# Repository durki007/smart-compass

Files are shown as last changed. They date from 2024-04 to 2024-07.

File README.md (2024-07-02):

# Smart Compass - Inteligentne urządzenie do nawigacji
## O projekcie
Projekt Smart Compass był realizowany w ramach kursu "Projekt Zespołowy" na VI semestrze studiów inżynierskich, na kierunku Informatyka Techniczna na Politechnice Wrocławskiej.

Celem projektu było zaprojektowanie urządzenia elektronicznego, działającego w trybie autonomicznym, pozwalającego na nawigację po prostej trasie składającej się z dowolnej liczby kolejnych punktów.

## Stan końcowy projektu
W ramach projektu zostały wykonane:
- [Aplikacja mobilna](https://github.com/durki007/smart-compass/tree/main/app) wykonana w technologii `React Native`. 
- [Schemat układu elektronicznego](https://github.com/durki007/smart-compass/tree/main/hardware)
- [Firmware urządzenia](https://github.com/durki007/smart-compass/tree/main/hardware) w języku `C` i frameworku `ESP-IDF`.

> Poszczególne częsci projektu, oraz instrukcje kompilacji i uruchomienia znajdują się w podfolderach repozytorium.

## Autorzy
- Dominik Cybulski
- Michał Durkalec
- Stanisław Kurzyp

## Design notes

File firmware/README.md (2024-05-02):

# SmartCompass Firmware
## About
This is the firmware for the ESP32 microcontroller that is part of the **Smart Compass** project.
> BLE configuration is based on the [ESP-IDF nimble/bleprph example](https://github.com/espressif/esp-idf/tree/5a40bb8746633477c07ff9a3e90016c37fa0dc0c/examples/bluetooth/nimble/bleprph)

## Project structure
The project is organized as follows:
```
firmware/ 
│   main/ -- Application code entry point
│   components/
│   ├── sc_ble      -- BLE configuration and services
│   ├── sc_compass  -- Compass sensor driver
│   ├── sc_display  -- Display driver
│   ├── sc_gps      -- GPS sensor driver
```
The `main` folder contains the entry point of the application. All tasks are created and initialized here.

The `components` folder contains the drivers for the sensors and the BLE configuration.
Each component defines a set of functions to initialize, read, and write data to the sensor.

### Third party components
Refer to `.gitmodules` for exact information. 
>To avoid dependency issues, use the correct versions of components.

Components used:
- [lvgl v8.3](https://github.com/lvgl/lvgl.git)
- [lvgl_esp32_drivers](https://github.com/hiruna/lvgl_esp32_drivers.git)
Fork by [hiruna](https://github.com/hiruna) with some modifications to work with the latest version of `lvgl` and `esp-idf v.5.2`.
## Build
#### Prerequisites
- [ESP-IDF v.5.2.1](https://docs.espressif.com/projects/esp-idf/en/stable/esp32/get-started/index.html#manual-installation)
- [Python 3.11.2](https://www.python.org/downloads/release/python-3112/)
> When using `ESP-IDF-v5.2.1`: `Python3.11.2` must be used. This is related to a known [issue](https://github.com/espressif/esp-idf/issues/12519).
### Using ESP-IDF
Set target to `esp32`:
```bash
idf.py set-target esp32
```
Build
```bash
idf.py build
```
### CMake on Windows
#### Prerequisites
- [CMake](https://cmake.org/download/)
- Ninja (or other build system)
- [ESP-IDF v.5.2.1](https://docs.espressif.com/projects/esp-idf/en/stable/esp32/get-started/index.html#manual-installation)
with all related environment variables set.

Generate build files
```bash
mkdir build 
cd build
cmake -G Ninja ..
```
Build
```bash
ninja
```
All commands normally provided by `idf.py` can be used with `cmake` and `ninja` as well. For example, to configure the device:
```bash
ninja menuconfig
```

## Flash
```bash
idf.py -p PORT flash
```
Where `PORT` is the serial port where the ESP32 is connected. For example, on Windows, it could be `COM3`.

## References
- [ESP-IDF v5.2.1](https://docs.espressif.com/projects/esp-idf/en/stable/esp32/get-started/index.html#manual-installation)
- [ESP-IDF Build System](https://docs.espressif.com/projects/esp-idf/en/stable/esp32/api-guides/build-system.html) -- Building the project, configuring the device, defining components etc.

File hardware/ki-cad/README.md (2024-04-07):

# Pliki KiCad

Pliki w tym folderze zostały udostępnione w celu odtworzenia projektu schematu i ich edycji w programie KiCad.

### Lista plików
- compass-schematic.kicad_sh - Plik odpowiedzialny za schemat prototypu, skopiowany z projektu o nazwie compass-schematics 
- Compass.kicad_sym - Plik biblioteki symboli stworzonych ręcznie dla urządzeń peryferyjnych
- Compass.bak - Plik wygenerowany dla biblioteki symboli, o nie do końca znanej funkcji, załączony na wypadek problemów w z blblioteką (prawdopodobnie plik back-up)

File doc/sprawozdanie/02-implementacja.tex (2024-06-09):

\part{Implementacja}

\section{Projekt urządzenia}

Urządzenie zostało zaprojektowane z myślą o maksymalnej prostocie, w związku z czym nie występuje żadna magistrala, a wszystkie moduły podłączone są wedle architektury punkt-punkt. Głównym elementem urządzenia jest płytka prototypowa {\bf DevKitV4 ESP-WROOM-32E}, zawierająca zaprogramowaną logikę sterowania oraz wbudowany moduł Bluetooth/WiFi.\\

Do urządzeń peryferyjnych należą:
\begin{itemize}
    \item Wyświetlacz LCD Waveshare 1.8inch 128x160
    \item Magnetometr cyfrowy 3-osiowy HMC5883L
    \item GPS GY-NEO6MV2 z anteną
\end{itemize}

Schemat podłączenia wszystkich elementów zaprezentowano na rysunku \ref{fig:scheme:hardware}.

\begin{figure}[H]
    \centering
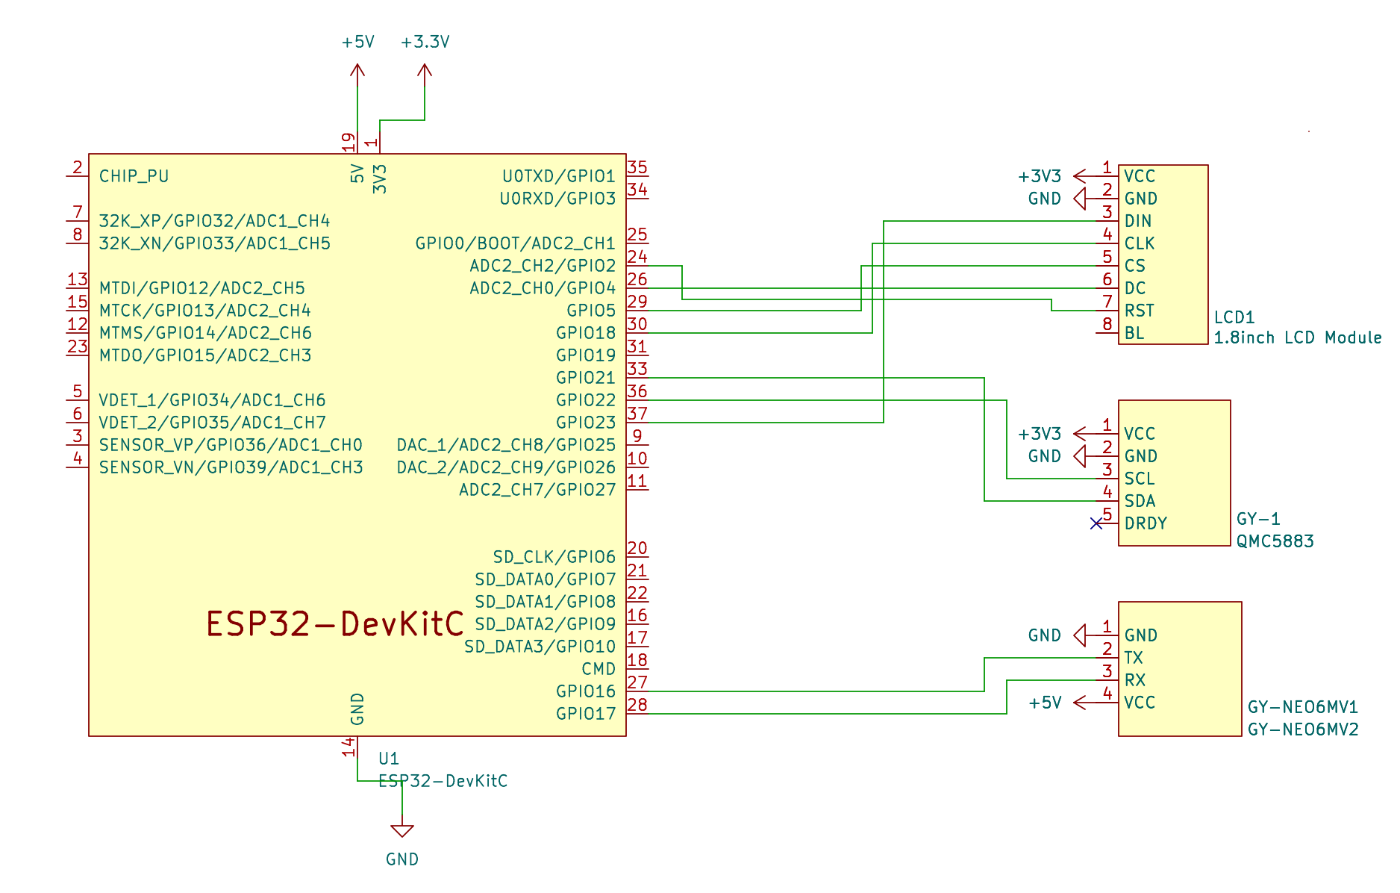
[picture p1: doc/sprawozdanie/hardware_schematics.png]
    
    \caption{Schemat prototypu urządzenia}
    \label{fig:scheme:hardware}
\end{figure}

\subsection{Kosztorys prototypu}
Kosztorys uwzględnia ceny głównych modułów urządzenia. Dotychczasowe koszty zostały pokryte przez członków grupy projektowej. Posiadamy również inne niezbędne części podstawowe, takie jak rezystory, kondensatory czy przyciski, które będą niezbędne przy testowaniu prototypu.

\begin{table}[h]
    \centering
    \begin{tabular}{|l|l|r|r|}
        \hline
        \textbf{Nazwa części} & \textbf{Typ}                 & \textbf{Cena detaliczna} & \textbf{Faktyczny koszt} \\ \hline
        Espressif DevKitV4    & ESP-WROOM-32E                & 35,99 zł                 & 35,99 zł                 \\ \hline
        GY-273                & Magnetometr cyfrowy 3-osiowy & 17,00 zł                 & 13,71 zł                 \\ \hline
        GY-NEO6MV2            & Moduł GPS z anteną           & 27,99 zł                 & 27,99 zł                 \\ \hline
        Waveshare 13892       & Wyświetlacz LCD 128x160px    & 33,90 zł                 & 0,00 zł                  \\ \hline
        \textbf{Razem}        &                              & \textbf{114,88 zł}       & \textbf{77,69 zł}        \\ \hline
    \end{tabular}
    \caption{Kosztorys prototypu}
\end{table}

\subsection{DevKitV4 ESP-WROOM-32E}

DevKitV4 ESP-WROOM-32E to zaawansowany moduł mikroprocesorowy z serii ESP32. Łączy w sobie  wysoką wydajność, niskie zużycie energii i wszechstronność. Wyposażony jest w podwójny rdzeń, obsługujący taktowanie do 240 MHz, oraz wbudowane Wi-Fi i Bluetooth. Posiada szeroki zakres interfejsów, zapewniając elastyczność w przypadku podłączania z modułami peryferyjnymi.

\subsection{LCD Waveshare 1.8inch 128x160}

Waveshare 1.8inch 128x160 to kolorowy wyświetlacz TFT o rozdzielczości 128x160 pikseli. Oferuje jasny i wyraźny obraz, umożliwiający wyświetlanie tekstu, grafiki i prostych animacji. Dane przesyłane są poprzez interfejs SPI.

\subsection{Mangetometr HMC5883L}

HMC5883L to trójosiowy magnetometr cyfrowy, który może mierzyć pole magnetyczne ziemi, co pozwala na określenie orientacji przestrzennej i wykorzystanie w roli kompasu. Dane odczytywane są poprzez interfejs I2C.

\subsection{GPS GY-NEO6MV2}

GY-NEO6MV2 to moduł GPS oparty na układzie NEO-6M, który umożliwia precyzyjne śledzenie pozycji geograficznej poprzez komunikację z satelitą za pomocą podłączonej anteny. Dane przezkazywane są poprzez standardowy interfejs UART.

\subsection{Napotkane problemy}

Podczas programowania oraz testowania komunikacji mikroprocesora z urządzeniami peryferyjnymi napotkano problemy z obsługą modułu GPS oraz magnetometru. \\

W przypadku połączenia z modułem GPS, wykryto wadliwość 2 z 4 zamówionych urządzeń - po wyznaczeniu oraz podłączeniu działających komponentów, nie wystąpiły już dalsze problemy. \\

W przypadku obsługi magnetometru pojawiały się problemy wydające się losowe w chwili próby nawiązania połączenia master-slave z modułem. Problemy te niekiedy zakłócały działanie całego programu załadowanego do mikroprocesora, niekiedy nie występowały, w innych przypadkach zaś powodowały błąd watchdoga w linii inicjalizacji sterownika I2C. Sterownik zawieszał się, oczekując transmisji na linii danych, które nigdy się nie pojawiały. Problem zidentyfikowano w błędzie implementacji sterownika I2C przez ESP-IDF. Użycie starszej wersji sterownika trwale usunęło problem. 

\section{Firmware}
Firmware aplikacji został napisany w języku C z wykorzystaniem platformy ESP-IDF \cite{esp-idf}.
ESP-IDF to oficjalne środowisko programistyczne dla platformy ESP32, które zawiera narzędzia do budowania, debugowania i wgrywania oprogramowania na urządzenie.

\subsection{Modularna struktura kodu} \label{sec:modularna-struktura-kodu}
Framework ESP-IDF pozwala na tworzenie projektów w sposób modułowy, co pozwala na łatwe dodawanie nowych funkcjonalności i niezależne testowanie poszczególnych komponentów.
W projekcie wyróżniono następujące moduły (komponenty):
\begin{itemize}
    \item \textbf{main} - moduł główny, inicjalizuje pozostałe moduły i definiuje zmienne współdzielone.
    \item \textbf{sc\_ble} - moduł odpowiedzialny za obsługę protokołu BLE. Zawiera definicje usług i charakterystyk GATT.
    \item \textbf{sc\_gps} - moduł obsługujący moduł GPS. Zawiera funkcje do odczytu współrzędnych geograficznych.
    \item \textbf{sc\_compass} - moduł obsługujący magnetometr. Zawiera funkcje do odczytu kierunku kompasu.
    \item \textbf{sc\_display} - moduł obsługujący wyświetlacz LCD. Zawiera funkcje do wyświetlania informacji na ekranie z wykorzystaniem biblioteki LVGL.
    \item \textbf{sc\_logic} - moduł odpowiedzialny za logikę aplikacji. Zawiera funkcje do obliczania kierunku i dystansu do celu.
    \item \textbf{lvgl} - moduł zawierający bibliotekę LVGL. \cite{lvgl-esp32-port} Zawiera konfigurację i funkcje pomocnicze do obsługi wyświetlacza.
    \item \textbf{lvgl\_esp32\_drivers} - moduł zawierający sterowniki dla ESP32 do biblioteki LVGL. \cite{lvgl-esp32-drivers}
\end{itemize}

\subsection{Architektura wielowątkowa}
Framework ESP-IDF jest oparty na architekturze FreeRTOS \cite{freertos-docs}, co pozwala na tworzenie wielowątkowych aplikacji.
Zawarta we frameworku wersja FreeRTOS pozwala na wykorzystanie dwóch rdzeni procesora ESP32, zapewniając równoległe wykonywanie zadań w dwóch wątkach.
Każdy z modułów aplikacji opisanych w sekcji \ref{sec:modularna-struktura-kodu} działa w osobnym wątku.

\subsubsection{Zmienne współdzielone}
Program zawiera dwie zmienne współdzielone odpowiedzialne za przechowywanie aktualnych danych na temat odczytów z sensorów oraz przechowywanie aktualnych danych do wyświetlenia na ekranie.

\begin{lstlisting}[language=C, caption=Definicja zmiennej dla odczytów sensorów]
typedef struct {
    SemaphoreHandle_t mutex;
    compass_position_t position;
    float bearing; // in radians
    float bearing_deg; // in degrees
    compass_path_t path;
    bool position_updated;
} compass_data_t;
\end{lstlisting}

\begin{lstlisting}[language=C, caption=Definicja zmiennej dla danych wynikowych]
typedef struct {
    SemaphoreHandle_t mutex;
    // Angle in 0.1 degrees - between 0 and 3600
    int16_t angle;
    // Next waypoint id
    uint16_t next_wp;
    // Distance to next waypoint in meters
    uint32_t distance;
    bool finished;
} display_data_t;
\end{lstlisting}

Każda zmienna posiada semafor, który zapewnia dostęp do zasobu w sposób atomowy, co zapobiega konfliktom między wątkami.

\subsection{Protokół komunikacji Bluetooth Low Energy (BLE)}
Protokół komunikacji BLE został zaimplementowany zgodnie ze standardem Bluetooth Core 4.2 \cite{bluetooth-core-spec-4-2} na platformie ESP32.
Użyto stosu i ESP-NimBLE \cite{esp-idf-nimble-docs}, który zapewni odpowiednie zarządzanie pamięcią oraz obsługę komunikacji BLE.
Stos ESP-NimBLE jest alternatywną wersją stosu Apache MyNewt Nimble \cite{apache-mynewt-docs}, przystosowaną do pracy z mikrokontrolerami producenta Espressif.

\subsubsection{Obsługa po stronie urządzenia}
Urządzenie wykorzystuje stos ESP-NimBLE do implementacji protokołu BLE, co pozwala na zmniejszenie zużycia pamięci.
Komunikacja z aplikacją mobilną opiera się na deklaracji usług i charakterystyk GATT, umożliwiając przesyłanie danych trasy w postaci tablic par współrzędnych geograficznych.

\begin{lstlisting}[language=C, caption=Definicja charakterystyki GATT]
static uint8_t gatt_svr_chr_val[MAX_CHAR_LEN];
static uint16_t gatt_svr_chr_val_handle;
static const ble_uuid128_t gatt_svr_chr_uuid =
        BLE_UUID128_INIT(0x00, 0x00, 0x00, 0x00, 0x11, 0x11, 0x11, 0x11,
                         0x22, 0x22, 0x22, 0x22, 0x33, 0x33, 0x33, 0x33);
\end{lstlisting}

\subsection{Napotkane problemy}
W trakcie rozwoju oprogramowania pojawiły się dwa główne problemy opisane w poniższych podrozdziałach.
\subsubsection{Konflikty między bibliotekami}
W trakcie rozwoju modułu odpowiedzialnego za komunikację z wyświetlaczem LCD pojawił się konflikt między:
\begin{itemize}
    \item Frameworkiem ESP-IDF
    \item Biblioteką LVGL,\cite{lvgl-esp32-port} która jest prostym silnikiem GUI
    \item Biblioteką LVGL ESP32 Drivers, \cite{lvgl-esp32-drivers} która zawiera sterowniki dla ESP32 do biblioteki LVGL
\end{itemize}
Początkowe próby integracji wszystkich trzech bibliotek w najnowszej wersji nie powiodły się,
co skutkowało koniecznością doboru kompatybilnych wersji bibliotek oraz dostosowaniem konfiguracji.
Proces naprawy konfliktów trwał kilka dni.

\subsubsection{Błąd w implementacji protokołu I2C w bibliotece ESP-IDF}
Do komunikacji z magnetometrem QMC5883 wykorzystano interfejs I2C \textit{(Inter Integrated Circut)}, który jest standardowym interfejsem komunikacyjnym dla urządzeń peryferyjnych.
Producent mikrokontrolera ESP32, firma Espressif, dostarcza bibliotekę do obsługi interfejsu I2C w ramach frameworku ESP-IDF.

W trakcie implementacji okazało się, że biblioteka ESP-IDF zawiera błąd w implementacji protokołu I2C, który uniemożliwiał poprawną komunikację z magnetometrem.
Dodatkowo, bład ten był niewykrywalny w procesie debugowania, co nie pozwalało na jednoznaczne zlokalizowanie problemu (mógł wynikać z błędu w kodzie, konfiguracji, podłęczeniu lub z uszkodzenia magnetometru).

Błąd naprawiono poprzez zastosowanie alternatywnej biblioteki do obsługi interfejsu I2C, co pozwoliło na poprawną komunikację z magnetometrem.

\section{Aplikacja mobilna}
Aplikacja mobilna spełnia następujące funkcjonalności:
\begin{itemize}
    \item rysowanie tras
    \item zapisywanie tras
    \item zarządzanie trasami
    \item nawiązywanie połączenia z urządzeniem SmartCompass
    \item przesyłanie tras do urządzenia SmartCompass
\end{itemize}

\subsection{Wykorzystane technologie}
Aplikacja została zrealizowana przy użyciu frameworku \textbf{React Native} \cite{react-native-docs} pozwalającego tworzyć jeden projekt, który następnie kompilowany jest do kodu aplikacji wykonywalnej na urządzeniach z Androidem jak i iOS. Ze względu na wymagania powiązane z uzyskaniem dostępu do modułu Bluetooth Low Energy urządzenia, zadecydowaliśmy się rozwijać naszą aplikację jedynie w kierunku systemu Android.
Ponadto wykorzystano platformę i zestaw narzędzi \textbf{Expo} \cite{expo-docs}, które upraszczają proces tworzenia, testowania i wdrażania aplikacji mobilnych.

\subsection{Wykorzystane biblioteki}

W aplikacji wykorzystano szereg bibliotek, które ułatwiły realizację poszczególnych funkcjonalności:

\begin{itemize}
    \item \textbf{react-native-async-storage} - Służy do przechowywania danych lokalnych na urządzeniu. Umożliwia łatwe zapisywanie i odczytywanie danych, takich jak ustawienia użytkownika czy trasy.
    \item \textbf{react-navigation} - Biblioteka do nawigacji w aplikacjach React Native. Umożliwia łatwe zarządzanie stosami ekranów, nawigację pomiędzy nimi oraz implementację różnorodnych wzorców nawigacji.
    \item \textbf{react-native-ble-plx} - Biblioteka do obsługi Bluetooth Low Energy (BLE). Umożliwia skanowanie, łączenie i komunikację z urządzeniami BLE, co jest kluczowe dla integracji z urządzeniem SmartCompass.
    \item \textbf{react-native-quick-base64} - Umożliwia szybkie kodowanie i dekodowanie danych w formacie base64, co jest przydatne przy przesyłaniu danych przez BLE.
    \item \textbf{react-native-vector-icons} - Biblioteka dostarczająca zestaw ikon do aplikacji. Umożliwia łatwe dodawanie ikon do przycisków, menu i innych elementów interfejsu użytkownika.
    \item \textbf{react-native-maps} - Biblioteka do integracji map w aplikacji. Umożliwia wyświetlanie map, rysowanie tras oraz interakcję z punktami na mapie.
    \item \textbf{react-native-reanimated} - Biblioteka do tworzenia płynnych i wydajnych animacji w aplikacji. Umożliwia tworzenie zaawansowanych animacji i interakcji, co poprawia ogólne wrażenia użytkownika.
\end{itemize}

\subsection{Tworzenie wersji \textit{release} aplikacji}
Pierwszym krokiem jest dodanie informacji takich jak nazwa, ikona, splash screen oraz konfiguracje specyficzne dla platformy Android do pliku \texttt{app.json}.

\begin{lstlisting}[caption=Plik app.json]
"expo": {
    "name": "app",
    "slug": "app",
    "version": "1.0.0",
    "orientation": "portrait",
    "icon": "./assets/icon.png",
    "plugins": [
      "react-native-ble-plx"
    ],
    "userInterfaceStyle": "light",
    "splash": {
      "image": "./assets/splash.png",
      "resizeMode": "contain",
      "backgroundColor": "#ffffff"
    },
}
\end{lstlisting}

należy również utworzyć konfigurację dla usługi \textbf{Expo Application Services (EAS)}, który jest częścią procesu budowania aplikacji. Konfigurację tą umieszcza się w pliku \texttt{eas.json}.

\begin{lstlisting}[caption=Plik eas.json]
{
  "cli": {
    "version": ">= 8.0.0"
  },
  "build": {
    "development": {
      "developmentClient": true,
      "distribution": "internal"
    },
    "preview": {
      "android": {
        "buildType": "apk"
      }
    },
    "production": {}
  },
  "submit": {
    "production": {}
  }
};
\end{lstlisting}

Dla klucza \texttt{preview} określamy typ budowania aplikacji jako \texttt{"apk"} dla platformy Android.
Następnie należy zalogować się do konta \textit{Expo}, a później, korzystając z komendy \texttt{'npx build -p android –profile preview'}, wygenerować plik \texttt{.apk}, który dostępny będzie do pobrania z konta użytkownika w platformie \textit{Expo}. Proces generowania pliku \texttt{.apk} jest zautomatyzowany i przeprowadzany przez narzędzie \textbf{Expo Build Service}. W przypadku naszej aplikacji rozwiązanie to znacząco ułatwia cały proces względem \textit{Bare Workflow}, czyli podejścia w którym nie wykorzystuje się frameworka \textit{Expo}.

\subsubsection{Różnice pomiędzy wersją testową, a \textit{release}}
Wersje testowe i release różnią się znacząco pod względem celu, konfiguracji, procesu budowania oraz dystrybucji. Wersje testowe są przeznaczone do szybkich iteracji i debugowania, zawierając narzędzia deweloperskie i umożliwiając natychmiastowe aktualizacje. Wersje release są zoptymalizowane pod kątem wydajności, stabilności i bezpieczeństwa, przeznaczone do dystrybucji do szerokiego grona użytkowników końcowych poprzez oficjalne sklepy aplikacji.

\subsection{Napotkane problemy}
Obsługa połączenia BLE z urządzeniem okazała się być trudniejsza niż zakładaliśmy, w szczególności monitorowanie sesji z poziomu aplikacji mobilnej. Cały proces wymaga również uzyskania odpowiednich pozwoleń od urządzenia na którym działa aplikacja, a proces testowania był utrudniony ponieważ posiadamy tylko jeden egzemplarz urządzenia SmartCompass. Ze względów technicznych UUID serwisu BLE naszego urządzenia SmartCompass został na sztywno ustawiony w aplikacji.

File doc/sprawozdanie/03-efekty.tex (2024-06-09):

\part{Efekty}

\section{Prototyp urządzenia}
Finalna wersja urządzenia została zmontowana na płytce prototypowej. (Rysunek \ref{fig:device})
Z przodu urządzenia widoczny jest wyświetlacz LCD i ceramiczna antena modułu GPS, z tyłu znajdują się mikrokontrolej na płytce prototypowej, moduł GPS i moduł magnetometru.
Prototyp korzysta z zasilania zewnętrznego poprzez kabel USB.

\begin{figure}[h]
    \centering
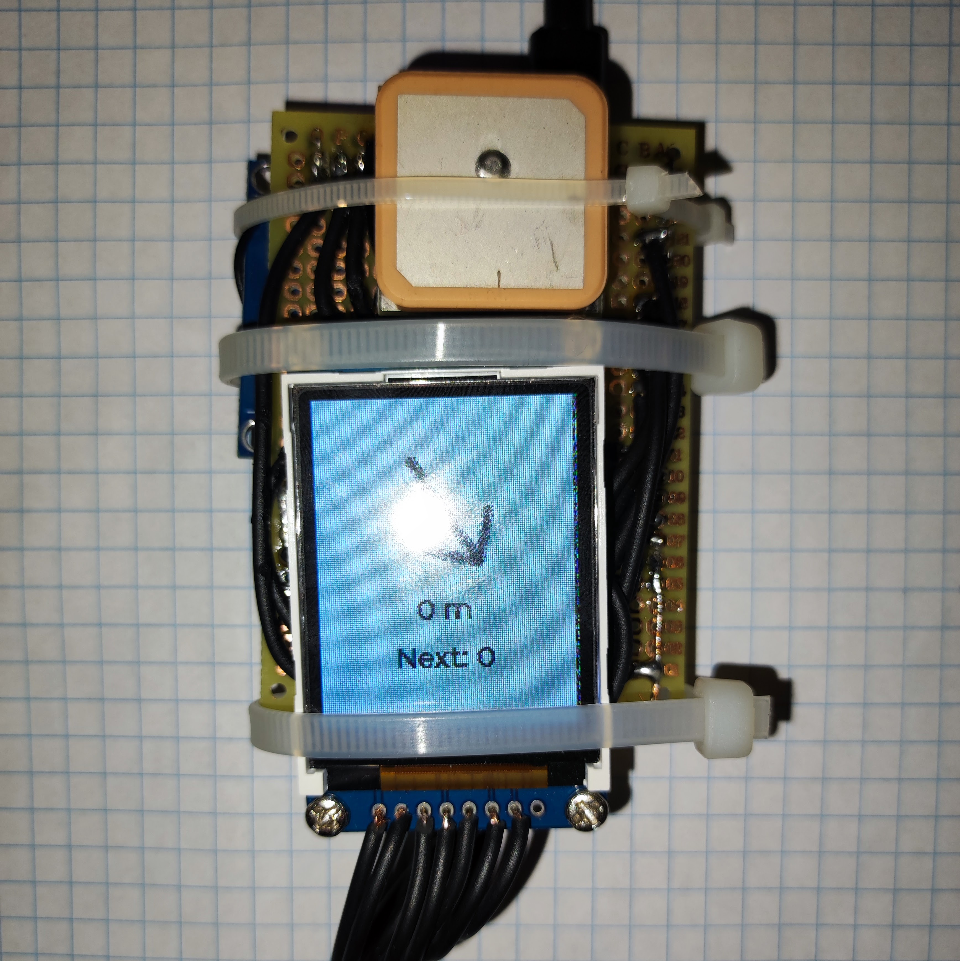
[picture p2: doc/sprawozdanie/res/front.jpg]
    
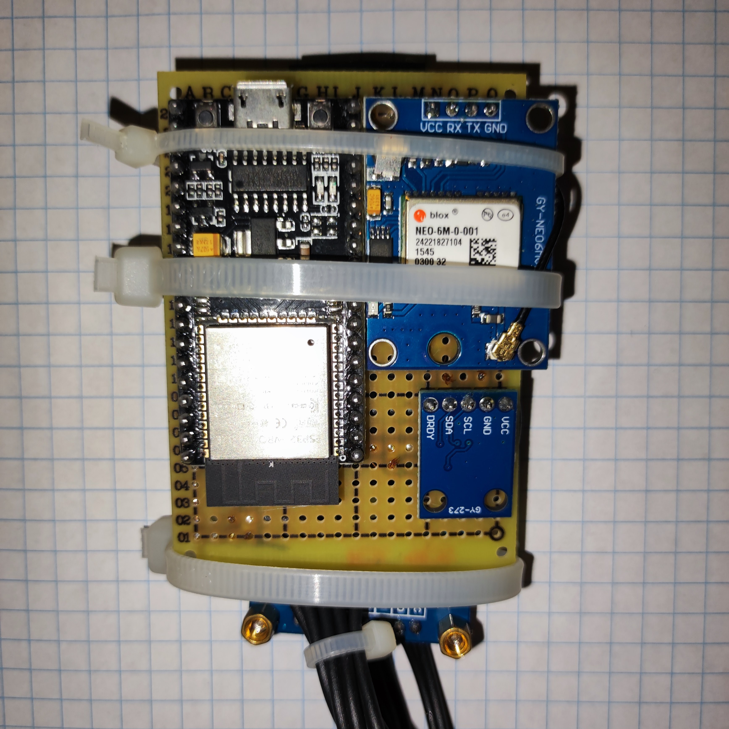
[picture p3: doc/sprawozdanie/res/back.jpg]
    
    \caption{Prototyp urządzenia (widok z przodu i z tyłu)}
    \label{fig:device}
\end{figure}

\subsection{Funkcjonalności}
W aktualnej wersji urządzenie jest w stanie:
\begin{itemize}
    \item Odczytywać dane z modułu GPS i magnetometru.
    \item Nawiązać połączenie w trybie BLE z aplikacją mobilną.
    \item Odbierać komendy od aplikacji mobilnej. (dane o nowej trasie)
    \item Wyświetlać na ekranie informacje o:
          \begin{itemize}
              \item Numerze następnego punktu na trasie
              \item Kierunku do następnego punktu
              \item Odległości do następnego punktu
              \item Zakończeniu nawigacji
          \end{itemize}
\end{itemize}

\section{Aplikacja mobilna}
\subsection{Widoki aplikacji}
\subsubsection{BLE connection}

\begin{figure}[H]
    \centering
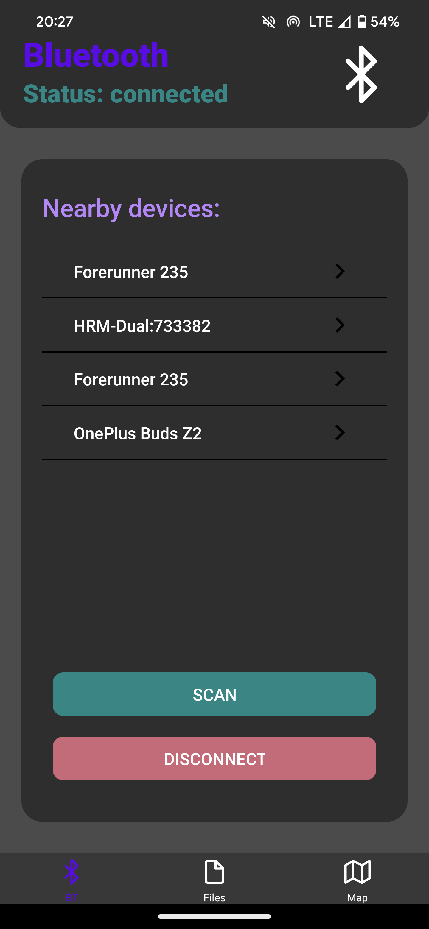
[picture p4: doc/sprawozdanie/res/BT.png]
    
    \caption{Ekran BLE connection}
\end{figure}

Widok ten pozwala użytkownikowi rozpocząć skanowanie pobliskich urządzeń BLE, a następnie wybrać jedno z nich i połączyć się z nim. Jeśli jest to urządzenie SmartCompass, to znaleziony zostanie udostępniany przez nie serwis BLE, którego UUID zapisane jest w aplikacji. Nawiązanie z nim połączenia umożliwi przesyłanie do tego urządzenia danych.
Na ekranie tym znajdują się również dwa przyciski:
\begin{itemize}
    \item \textbf{Przycisk Scan} - rozpoczyna skanowanie urządzeń
    \item \textbf{Przycisk Disconnect} - rozłącza z urządzeniem.
\end{itemize}

\subsubsection{Files}
\begin{figure}[H]
    \centering
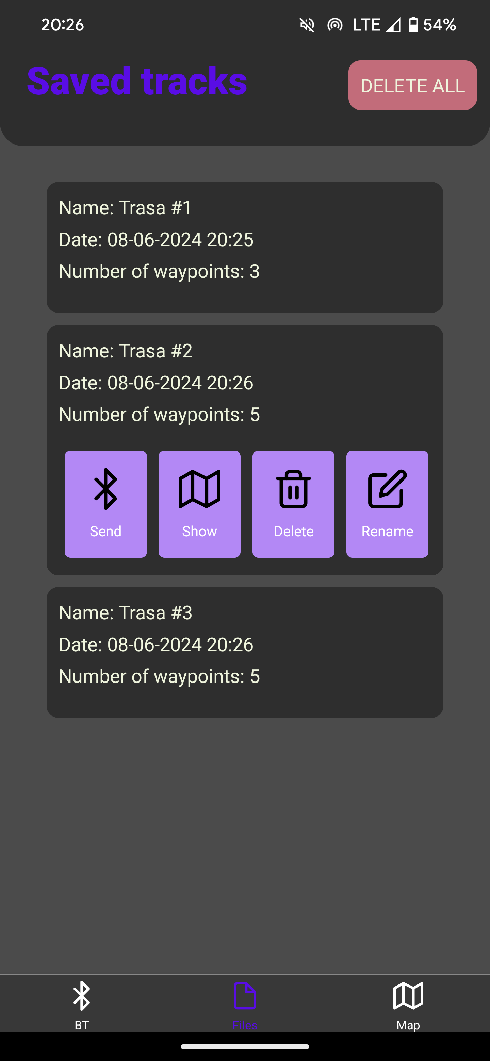
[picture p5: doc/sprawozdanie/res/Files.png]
    
    \caption{Ekran plików}
\end{figure}

Widok ten oferuje możliwość przeglądania zapisanych w urządzeniu tras

Po kliknięciu w trasę, rozwinie się menu z 4 przyciskami:
\begin{itemize}
    \item \textbf{delete} – usuwa wybraną trasę.
    \item \textbf{edit} – przenosi do widoku mapy i wyświetla w nim wybraną trasę pozwalając na jej edycję.
    \item \textbf{send} – pozwala przesłać wybraną trasę do urządzenia SmartCompass jeśli jest ono połączone.
\end{itemize}

\subsubsection{Map}
\begin{figure}[H]
    \centering
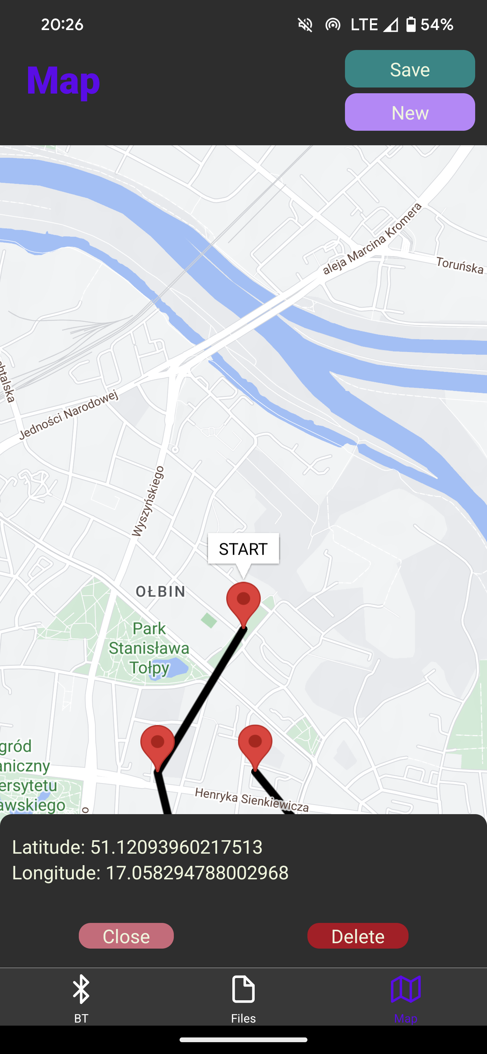
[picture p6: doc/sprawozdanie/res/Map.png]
    
    \caption{Ekran Mapy}
\end{figure}
Widok mapy oferuje możliwość rysowania trasy, dodawania nowej trasy oraz zapisu obecnie narysowanej trasy. W tym celu wykorzystywane są poniższe przyciski:

\begin{itemize}
    \item \textbf{NEW} – wyczyszczenie punktów na mapie, jeśli trasa jest zapisana nie zostanie ona utracona. Pozwala na rysowanie nowej trasy
    \item \textbf{SAVE} – służy do zapisu aktualnie narysowanej trasy. Po kliknięciu pojawi się okienko z miejscem na wpisanie nazwy trasy. Trasa zapisana zostanie do wewnętrznej, statycznej pamięci urządzenia i widoczna będzie w widoku \textbf{Files} po restarcie aplikacji.
\end{itemize}
Ponadto do interakcji z mapą użytkownik wykorzystuje następujące gesty:
\begin{itemize}
    \item \textbf{przytrzymanie palcem w pustym miejscu na mapie} – dodanie nowego punktu
    \item \textbf{dłuższe przytrzymanie znacznika punktu} – przejście w tryb przenoszenia punktu poprzez przesuwanie palcem po ekranie. Znacznik zostanie upuszczony po oderwaniu palca od ekranu
    \item \textbf{kliknięcie w znacznik} – nad znacznikiem wyświetli się małe pole z jego numerem na trasie lub napisem \textit{START/META}. Ponadto na dole ekranu wyświetli się okno z dokładną lokalizacją punktu. Kliknięcie w puste miejsce na mapie spowoduje zamknięcie tego okna i zniknięcie pola nad znacznikiem.
\end{itemize}

\section{Możliwości rozwoju}
\subsection{Rozwój urządzenia}
W aktualnej wersji prototyp spełnia wszystkie wymagania prototypu funkcjonalnego, tzn. pozwala na:
\begin{itemize}
    \item Weryfikacje komunikacji między wszystkimi komponentami.
    \item Weryfikacje działania algorytmu nawigacji.
    \item Weryfikacje działania aplikacji mobilnej.
    \item Sprawdzenie trafności pomysłu na projekt. \textit{(Czy urządzenie w praktyce ma sens?)}
    \item Szybką iterację nad projektem. \textit{(Wymiana modułów i sensorów bez dużych nakładów czasowych i finansowych)}
\end{itemize}
Następnym krokiem w rozwoju urządzenia byłoby przygotowanie produktu do produkcji seryjnej. Wymagałoby to:
\begin{itemize}
    \item Zaprojektowanie dedykowanego układu PCB, który zintegruje wszystkie komponenty i umożliwi miniaturyzacje urządzenia.
    \item Zaprojektowanie dedykowanego modułu zasilania, który będzie spełniał wymagania dotyczące czasu pracy urządzenia.
    \item Zaprojektowanie obudowy, która będzie spełniała wymagania wodoodporności i odporności na wstrząsy.
\end{itemize}
Dodatkowo, w celu zwiększenia atrakcyjności produktu można wprowadzić usprawnienia:
\begin{itemize}
    \item W interfejsie użytkownika - dodanie dodatkowych informacji na wyświetlaczu, prezentacja informacji w bardziej atrakcyjny sposób.
    \item W stabilności działania - poprawa algorytmów nawigacji, zwiększenie dokładności pomiarów.
    \item W zużyciu energii - zastosowanie bardziej energooszczędnych komponentów, optymalizacja algorytmów.
    \item W funkcjonalności - dodanie dodatkowych funkcji, takich jak zapisywanie przebytej trasy, zapisywanie punktów zainteresowania, przechowywanie większej liczby tras.
\end{itemize}

\subsection{Rozwój aplikacji mobilnej}
Aplikacja realizuje zdefiniowane dla niej założenia. Potencjał na rozwój znajduje się w interfejsie użytkownika i, pomimo że jest kompletny, można wprowadzić zmiany, które poprawią ogólne wrażenia oraz intuicyjność korzystania z aplikacji dla użytkownika końcowego.

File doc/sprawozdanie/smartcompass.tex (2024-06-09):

\documentclass[titlepage]{article}

\usepackage[utf8]{inputenc}
\usepackage[polish]{babel}
\usepackage{polski}
\usepackage{geometry}
\geometry{
    a4paper,
    margin=1in
}

\usepackage{amsmath,amssymb,amsthm,amsfonts}
\usepackage{lipsum}
\usepackage{hyperref}
\hypersetup{
pdftitle={Cybulski, Durkalec, Kurzyp - SmartCompass},
}
\usepackage{float}
\usepackage{placeins}
\usepackage{tabularx}
\usepackage{graphicx}
\usepackage{url}
\usepackage{listings}
\usepackage{color}
\usepackage{parskip}
\usepackage[counterclockwise]{rotating}
\graphicspath{ {./res/} }
% Headers and footers
\usepackage{fancyhdr, lastpage}
\pagestyle{fancy}
\lhead{PWr}
\chead{SmartCompass}
\rhead{Projekt Zespołowy, Lato 2024} 
% Footers
\lfoot{D. Cybulski, M. Durkalec, S. Kurzyp}
\cfoot{}
\rfoot{Strona \thepage \hspace{1pt} z \pageref{LastPage}}
\setlength{\headheight}{15pt}

% Custom footer and header on new chapter pages
\usepackage{etoolbox}
\patchcmd{\chapter}{\thispagestyle{plain}}{\thispagestyle{fancy}}{}{}

% Custom commands
% Display info about module
\newenvironment{module}[1]
{
    \begin{minipage}{\textwidth}
    \begin{equation*}
        #1
    \end{equation*}
    \begin{center}
    \renewcommand{\arraystretch}{1.2}
}
{
\end{center}
\end{minipage}
\vspace{1em}
\\ \noindent
}

\title{
SmartCompass \\ \vspace{5px}
\large Inteligentne urządzenie do nawigacji 
}
\author{
    \makebox[3.5cm]{Dominik Cybulski}  - \texttt{\href{mailto:255520@student.pwr.edu.pl}{255520@student.pwr.edu.pl}} \\
    \makebox[3.5cm]{Michał Durkalec}   - \texttt{\href{mailto:263917@student.pwr.edu.pl}{263917@student.pwr.edu.pl}} \\
    \makebox[3.5cm]{Stanisław Kurzyp}  - \texttt{\href{mailto:264477@student.pwr.edu.pl}{264477@student.pwr.edu.pl}}
}
\date{
\textbf{Prowadzący:} prof. Robert Burduk \\
Politechnika Wrocławska \\
Semestr letni 2024
}

\begin{document}

\maketitle

\tableofcontents

\include{01-zarzadzanie}
\include{02-implementacja}
\include{03-efekty}

\bibliographystyle{plain}
\bibliography{refs}

\end{document}

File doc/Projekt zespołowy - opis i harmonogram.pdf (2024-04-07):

# Projekt zespołowy

## Inteligentne urządzenie do nawigacji

Cybulski Dominik | 255520@student.pwr.edu.pl
Durkalec Michał | 263917@student.pwr.edu.pl
Kurzyp Stanisław | 264477@student.pwr.edu.pl

# Założenia projektowe

Celem projektu będzie zaprojektowanie i zbudowanie urządzenia służącego do nawigacji pieszej. Urządzenie będzie składało się z mikroprocesora z modułem Bluetooth, modułu GPS, wyświetlacza LCD oraz układu zasilającego. Konfiguracja będzie odbywała się za pomocą aplikacji mobilnej, w której możliwe będzie zaplanowanie trasy i wgranie jej do urządzenia.
Po skonfigurowaniu trasy, urządzenie będzie wskazywało kierunek i odległość do następnego punktu (na wyświetlaczu LCD).

## Wymagania projektowe - tablica MoSCoW

Must have:
1. Urządzenie poprawnie wskazuje kierunek i odległość do kolejnych punktów trasy.
2. Aplikacja pozwala na zaplanowanie trasy na mapie i wgranie jej do pamięci urządzenia.
3. Po konfiguracji urządzenie działa autonomicznie. (nie wymaga komunikacji
z aplikacją)
Should have:
1. Bateria pozwala na całodzienne korzystanie z urządzenia (około 8h)
2. Urządzenie implementuje mechanizmy pozwalające na zmniejszenie zużycia energii (np. wygaszanie ekranu).
3. Aktualny stan nawigacji jest zapisywany w pamięci nieulotnej, co pozwala na wznowienie korzystania z urządzenia nawet po utracie zasilania.
Could have:
1. Urządzenie zapisuje swoje aktualne położenie i pozwala na zgranie przebiegu trasy do aplikacji.
2. Aplikacja wyświetla historię przebytych tras, razem z czasami przejścia.
3. Realizacja urządzenia na samodzielnie zaprojektowanej płytce PCB
Won’t have:
1. Urządzenie nie posiada interaktywnego interfejsu użytkownika, wyświetla tylko aktualny stan trasy.

# Harmonogram realizacji projektu

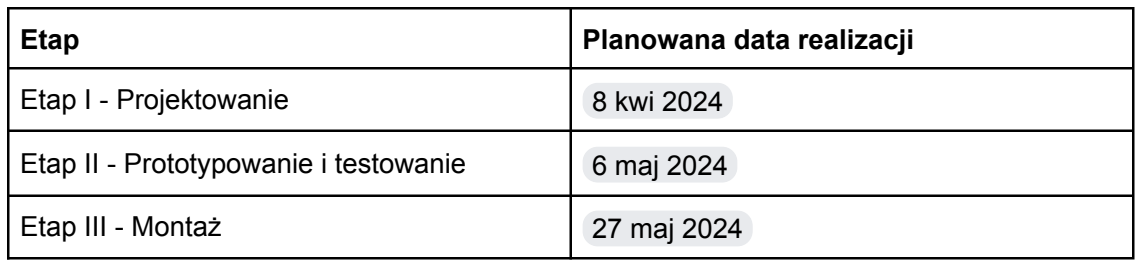
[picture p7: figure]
Etap; Planowana data realizacji; Etap I - Projektowanie; 8 kwi 2024; Etap III - Montaż; 27 maj 2024

Etap II - Prototypowanie i testowanie | 6 maj 2024

## Etap I - Projektowanie urządzenia i aplikacji

### Cel etapu

Opracowanie listy niezbędnych komponentów elektronicznych, projektu aplikacji mobilnej oraz protokołu komunikacji między urządzeniem, a aplikacją.

### Zadania do zrealizowania

- Opracowanie listy niezbędnych komponentów elektronicznych.
- Analiza komponentów dostępnych na rynku, wybór komponentów.
- Projekt układu elektronicznego.
- Wybór technologii programowania aplikacji mobilnej.
- Projektowanie widoków aplikacji mobilnej.
- Opracowanie i opisanie protokołu komunikacji między aplikacją, a urządzeniem.
- Analiza możliwości montażu układu elektronicznego

### Efekty

1. Kompletna lista niezbędnych komponentów elektronicznych i kosztorys.
2. Wybrana technologia realizacji aplikacji mobilnej.
3. Układ urządzenia.
4. Protokół komunikacji między urządzeniem, a aplikacją.

## Etap II - Prototypowanie i testowanie

### Cel etapu

Zbudowanie układu na płytce prototypowej, programowanie firmaware’u. Programowanie aplikacji mobilnej.

### Zadania do zrealizowania

- Zakup komponentów elektronicznych.
- Montaż układu na płytce prototypowej.
- Programowanie urządzenia.
- Programowanie aplikacji mobilnej.

- Testy komunikacji między aplikacją, a urządzeniem.

### Efekty

Działający prototyp urządzenia i aplikacji.

## Etap III - Montaż

### Cel etapu

Montaż układu w wybranej technologii. (through-hole lub SFM) Umieszczenie układu w obudowie. Wydanie wersji produkcyjnej aplikacji.

### Zadania do zrealizowania

- Montaż układu, lub zlecenie montażu firmie zewnętrznej.
- Budowa obudowy urządzenia. (druk 3D)
- Przygotowanie wersji release aplikacji mobilnej.

### Efekty

Działające urządzenie i aplikacja.

# Ryzyka w realizacji projektu

Ryzyko | Prawdopodobieństwo wystąpienia | Wycena ryzyka | Plan działania
Odejście członków zespołu | Bardzo niskie | Bardzo niskie | Akceptacja ryzyka
Ograniczony budżet | Średnie | Wysokie | Opracowanie szczegółowego kosztorysu. Pozyskanie środków od Politechniki.
Opóźnienia w dostawie komponentów | Średnie | Średnie | Uwzględnienie potencjalnego opóźnienia w harmonogramie realizacji.
Opóźnienia w montażu układu (PCB) | Średnie | Średnie | Uwzględnienie potencjalnego opóźnienia w harmonogramie realizacji. Opracowanie alternatywnego planu montażu.

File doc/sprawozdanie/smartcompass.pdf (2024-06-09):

## SmartCompass

Inteligentne urządzenie do nawigacji

Dominik Cybulski - 255520@student.pwr.edu.pl Michał Durkalec - 263917@student.pwr.edu.pl Stanisław Kurzyp - 264477@student.pwr.edu.pl

Prowadzący: prof. Robert Burduk Politechnika Wrocławska
Semestr letni 2024

PWr | SmartCompass | Projekt Zespołowy, Lato 2024

## Spis treści

I | Zarządzanie projektem | 3
1 Założenia projektowe | 3
2 Ryzyka projektowe | 3
3 Harmonogram projektu | 4
4 Zarządzanie zespołem | 5
II | Implementacja | 6
5 Projekt urządzenia | 6
6 Firmware | 7
7 Aplikacja mobilna | 9
III | Efekty | 12
8 Prototyp urządzenia | 12
9 Aplikacja mobilna | 13
D. Cybulski, M. Durkalec, S. Kurzyp | Strona 1 z 16

10 Możliwości rozwoju | 14
D. Cybulski, M. Durkalec, S. Kurzyp | Strona 2 z 16

## Część I

# Zarządzanie projektem

## 1 Założenia projektowe

Celem projektu będzie zaprojektowanie i zbudowanie urządzenia służącego do nawigacji pieszej. Urządzenie będzie składało się z mikroprocesora z modułem Bluetooth, modułu GPS, wyświetlacza LCD oraz układu zasilającego. Konfiguracja będzie odbywała się za pomocą aplikacji mobilnej, w której możliwe będzie zaplanowanie trasy i wgranie jej do urządzenia. Po skonfigurowaniu trasy, urządzenie będzie wskazywało kierunek i odległość do następnego punktu (na wyświetlaczu LCD).

### 1.1 Wymagania projektowe

Wymagania projektowe zostały określone za pomocą tablicy MoSCoW:
- Must have:

– Urządzenie poprawnie wskazuje kierunek i odległość do kolejnych punktów trasy.

– Aplikacja pozwala na zaplanowanie trasy na mapie i wgranie jej do pamięci urządzenia.

– Po konfiguracji urządzenie działa autonomicznie, bez potrzeby komunikacji z aplikacją.
- Should have:

– Bateria pozwala na całodzienne korzystanie z urządzenia (około 8 godzin).

– Urządzenie implementuje mechanizmy zmniejszające zużycie energii (np. wygaszanie ekranu).

– Aktualny stan nawigacji jest zapisywany w pamięci nieulotnej, co umożliwia wznowienie korzystania z urządzenia po utracie zasilania.
- Could have:

– Urządzenie zapisuje aktualne położenie i pozwala na zgranie przebiegu trasy do aplikacji.

– Aplikacja wyświetla historię przebytych tras razem z czasami przejścia.

– Realizacja urządzenia na samodzielnie zaprojektowanej płytce PCB.
- Won’t have:

– Urządzenie nie posiada interaktywnego interfejsu użytkownika, wyświetla jedynie aktualny stan trasy.

## 2 Ryzyka projektowe

Realizacja projektu wiąże się z kilkoma ryzykami, które zostały zidentyfikowane i ocenione pod względem prawdopodobieństwa wystąpienia oraz wpływu na projekt. Poniżej przedstawiono główne ryzyka oraz planowane działania w celu ich minimalizacji.

### 2.1 Odejście członków zespołu

- Prawdopodobieństwo: Bardzo niskie
- Wpływ: Bardzo niski
- Plan działania: Akceptacja ryzyka ze względu na niskie prawdopodobieństwo i wpływ.
D. Cybulski, M. Durkalec, S. Kurzyp | Strona 3 z 16

### 2.2 Ograniczony budżet

- Prawdopodobieństwo: Średnie
- Wpływ: Wysokie
- Plan działania: Opracowanie szczegółowego kosztorysu oraz pozyskanie dodatkowych środków finansowych od Politechniki.

### 2.3 Opóźnienia w dostawie komponentów

- Prawdopodobieństwo: Średnie
- Wpływ: Średnie
- Plan działania: Uwzględnienie potencjalnych opóźnień w harmonogramie realizacji oraz opracowanie alternatywnych planów montażu.

### 2.4 Opóźnienia w montażu układu (PCB)

- Prawdopodobieństwo: Średnie
- Wpływ: Średnie
- Plan działania: Uwzględnienie potencjalnych opóźnień w harmonogramie realizacji oraz opracowanie alternatywnego planu montażu.

### 2.5 Niewystarczające umiejętności

- Prawdopodobieństwo: Średnie
- Wpływ: Średnie
- Plan działania: Akceptacja ryzyka oraz regularne szkolenia i konsultacje w zespole.

### 2.6 Skomplikowana dokumentacja techniczna komponentów

- Prawdopodobieństwo: Średnie
- Wpływ: Niskie
- Plan działania: Wybór innych komponentów lub korzystanie z nieoficjalnych dokumentacji i wsparcia społeczności online.

## 3 Harmonogram projektu

Projekt został podzielony na trzy główne etapy:
- Etap I - Projektowanie (do 8 kwietnia 2024)

– Opracowanie listy komponentów elektronicznych.

– Analiza i wybór komponentów.

– Projekt układu elektronicznego.

– Wybór technologii programowania aplikacji mobilnej.

– Projektowanie widoków aplikacji mobilnej.

– Opracowanie protokołu komunikacji między urządzeniem a aplikacją.
- Etap II - Prototypowanie i testowanie (do 6 maja 2024)

– Zakup komponentów.

– Montaż układu na płytce prototypowej.

– Programowanie urządzenia i aplikacji mobilnej.

D. Cybulski, M. Durkalec, S. Kurzyp | Strona 4 z 16

– Testy komunikacji między aplikacją a urządzeniem.
- Etap III - Montaż (do 27 maja 2024)

– Montaż układu w wybranej technologii.

– Budowa obudowy urządzenia.

– Przygotowanie wersji produkcyjnej aplikacji mobilnej.

## 4 Zarządzanie zespołem

### 4.1 Podział zadań

Przed rozpoczęciem projektu został ustalony następujący podział zadań:
- Dominik Cybulski, Michał Durkalec:
Projektowanie układu elektronicznego, programowanie urządzenia.
- Stanisław Kurzyp:
Projektowanie aplikacji mobilnej.

### 4.2 Planowanie pracy

Do planowania poszczególnych zadań oraz monitorowania postępów wykorzystane zostało narzędzie Github Projects [7], które pozwala na

- Tworzenie zadań i przypisywanie ich do członków zespołu.
- Planowanie terminów realizacji zadań.
- Monitorowanie postępów prac.
- Łączenie zadań z konkretnymi gałęziami kodu w systemie kontroli wersji.
D. Cybulski, M. Durkalec, S. Kurzyp | Strona 5 z 16

## Część II

# Implementacja

## 5 Projekt urządzenia

Urządzenie zostało zaprojektowane z myślą o maksymalnej prostocie, w związku z czym nie występuje żadna magistrala, a wszystkie moduły podłączone są wedle architektury punkt-punkt. Głównym elementem urządzenia jest płytka prototypowa DevKitV4 ESP-WROOM-32E, zawierająca zaprogramowaną logikę sterowania oraz wbudowany moduł Bluetooth/WiFi.

Do urządzeń peryferyjnych należą:
- Wyświetlacz LCD Waveshare 1.8inch 128x160
- Magnetometr cyfrowy 3-osiowy HMC5883L
- GPS GY-NEO6MV2 z anteną

Schemat podłączenia wszystkich elementów zaprezentowano na rysunku 1.


Rysunek 1: Schemat prototypu urządzenia

### 5.1 Kosztorys prototypu

Kosztorys uwzględnia ceny głównych modułów urządzenia. Dotychczasowe koszty zostały pokryte przez członków grupy projektowej. Posiadamy również inne niezbędne części podstawowe, takie jak rezystory, kondensatory czy przyciski, które będą niezbędne przy testowaniu prototypu.

Nazwa części | Typ | Cena detaliczna | Faktyczny koszt
Espressif DevKitV4 | ESP-WROOM-32E | 35,99 zł | 35,99 zł
GY-273 | Magnetometr cyfrowy 3-osiowy | 17,00 zł | 13,71 zł
GY-NEO6MV2 | Moduł GPS z anteną | 27,99 zł | 27,99 zł
Waveshare 13892 | Wyświetlacz LCD 128x160px | 33,90 zł | 0,00 zł
Razem | | 114,88 zł | 77,69 zł

Tabela 1: Kosztorys prototypu

D. Cybulski, M. Durkalec, S. Kurzyp | Strona 6 z 16

### 5.2 DevKitV4 ESP-WROOM-32E

DevKitV4 ESP-WROOM-32E to zaawansowany moduł mikroprocesorowy z serii ESP32. Łączy w sobie wysoką wydajność, niskie zużycie energii i wszechstronność. Wyposażony jest w podwójny rdzeń, obsługujący taktowanie do 240 MHz, oraz wbudowane Wi-Fi i Bluetooth. Posiada szeroki zakres interfejsów, zapewniając elastyczność w przypadku podłączania z modułami peryferyjnymi.

### 5.3 LCD Waveshare 1.8inch 128x160

Waveshare 1.8inch 128x160 to kolorowy wyświetlacz TFT o rozdzielczości 128x160 pikseli. Oferuje jasny i wyraźny obraz, umożliwiający wyświetlanie tekstu, grafiki i prostych animacji. Dane przesyłane są poprzez interfejs SPI.

### 5.4 Mangetometr HMC5883L

HMC5883L to trójosiowy magnetometr cyfrowy, który może mierzyć pole magnetyczne ziemi, co pozwala na określenie orientacji przestrzennej i wykorzystanie w roli kompasu. Dane odczytywane są poprzez interfejs I2C.

### 5.5 GPS GY-NEO6MV2

GY-NEO6MV2 to moduł GPS oparty na układzie NEO-6M, który umożliwia precyzyjne śledzenie pozycji geograficznej poprzez komunikację z satelitą za pomocą podłączonej anteny. Dane przezkazywane są poprzez standardowy interfejs UART.

### 5.6 Napotkane problemy

Podczas programowania oraz testowania komunikacji mikroprocesora z urządzeniami peryferyjnymi napotkano problemy z obsługą modułu GPS oraz magnetometru.

W przypadku połączenia z modułem GPS, wykryto wadliwość 2 z 4 zamówionych urządzeń - po wyznaczeniu oraz podłączeniu działających komponentów, nie wystąpiły już dalsze problemy.

W przypadku obsługi magnetometru pojawiały się problemy wydające się losowe w chwili próby nawiązania połączenia master-slave z modułem. Problemy te niekiedy zakłócały działanie całego programu załadowanego do mikroprocesora, niekiedy nie występowały, w innych przypadkach zaś powodowały błąd watchdoga w linii inicjalizacji sterownika I2C. Sterownik zawieszał się, oczekując transmisji na linii danych, które nigdy się nie pojawiały. Problem zidentyfikowano w błędzie implementacji sterownika I2C przez ESP-IDF. Użycie starszej wersji sterownika trwale usunęło problem.

## 6 Firmware

Firmware aplikacji został napisany w języku C z wykorzystaniem platformy ESP-IDF [5]. ESP-IDF to oficjalne środowisko programistyczne dla platformy ESP32, które zawiera narzędzia do budowania, debugowania i wgrywania oprogramowania na urządzenie.

### 6.1 Modularna struktura kodu

Framework ESP-IDF pozwala na tworzenie projektów w sposób modułowy, co pozwala na łatwe dodawanie nowych funkcjonalności i niezależne testowanie poszczególnych komponentów. W projekcie wyróżniono następujące moduły (komponenty):

- main - moduł główny, inicjalizuje pozostałe moduły i definiuje zmienne współdzielone.
- sc ble - moduł odpowiedzialny za obsługę protokołu BLE. Zawiera definicje usług i charakterystyk GATT.
- sc gps - moduł obsługujący moduł GPS. Zawiera funkcje do odczytu współrzędnych geograficznych.
D. Cybulski, M. Durkalec, S. Kurzyp | Strona 7 z 16

- sc compass - moduł obsługujący magnetometr. Zawiera funkcje do odczytu kierunku kompasu.
- sc display - moduł obsługujący wyświetlacz LCD. Zawiera funkcje do wyświetlania informacji na ekranie z wykorzystaniem biblioteki LVGL.
- sc logic - moduł odpowiedzialny za logikę aplikacji. Zawiera funkcje do obliczania kierunku i dystansu do celu.
- lvgl - moduł zawierający bibliotekę LVGL. [9] Zawiera konfigurację i funkcje pomocnicze do obsługi wyświetlacza.
- lvgl esp32 drivers - moduł zawierający sterowniki dla ESP32 do biblioteki LVGL. [8]

### 6.2 Architektura wielowątkowa

Framework ESP-IDF jest oparty na architekturze FreeRTOS [1], co pozwala na tworzenie wielowątkowych aplikacji. Zawarta we frameworku wersja FreeRTOS pozwala na wykorzystanie dwóch rdzeni procesora ESP32, zapewniając równoległe wykonywanie zadań w dwóch wątkach. Każdy z modułów aplikacji opisanych w sekcji 6.1 działa w osobnym wątku.

### 6.2.1 Zmienne współdzielone

Program zawiera dwie zmienne współdzielone odpowiedzialne za przechowywanie aktualnych danych na temat odczytów z sensorów oraz przechowywanie aktualnych danych do wyświetlenia na ekranie.

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

Każda zmienna posiada semafor, który zapewnia dostęp do zasobu w sposób atomowy, co zapobiega konfliktom między wątkami.

### 6.3 Protokół komunikacji Bluetooth Low Energy (BLE)

Protokół komunikacji BLE został zaimplementowany zgodnie ze standardem Bluetooth Core 4.2 [3] na platformie ESP32. Użyto stosu i ESP-NimBLE [4], który zapewni odpowiednie zarządzanie pamięcią oraz obsługę komunikacji BLE. Stos ESP-NimBLE jest alternatywną wersją stosu Apache MyNewt Nimble [2], przystosowaną do pracy z mikrokontrolerami producenta Espressif.

### 6.3.1 Obsługa po stronie urządzenia

Urządzenie wykorzystuje stos ESP-NimBLE do implementacji protokołu BLE, co pozwala na zmniejszenie zużycia pamięci. Komunikacja z aplikacją mobilną opiera się na deklaracji usług i charakterystyk GATT, umożliwiając przesyłanie danych trasy w postaci tablic par współrzędnych geograficznych.

D. Cybulski, M. Durkalec, S. Kurzyp | Strona 8 z 16

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

### 6.4 Napotkane problemy

W trakcie rozwoju oprogramowania pojawiły się dwa główne problemy opisane w poniższych podrozdziałach.

### 6.4.1 Konflikty między bibliotekami

W trakcie rozwoju modułu odpowiedzialnego za komunikację z wyświetlaczem LCD pojawił się konflikt między:
- Frameworkiem ESP-IDF
- Biblioteką LVGL,[9] która jest prostym silnikiem GUI
- Biblioteką LVGL ESP32 Drivers, [8] która zawiera sterowniki dla ESP32 do biblioteki LVGL

Początkowe próby integracji wszystkich trzech bibliotek w najnowszej wersji nie powiodły się, co skutkowało koniecznością doboru kompatybilnych wersji bibliotek oraz dostosowaniem konfiguracji. Proces naprawy konfliktów trwał kilka dni.

### 6.4.2 Błąd w implementacji protokołu I2C w bibliotece ESP-IDF

Do komunikacji z magnetometrem QMC5883 wykorzystano interfejs I2C (Inter Integrated Circut), który jest standardowym interfejsem komunikacyjnym dla urządzeń peryferyjnych. Producent mikrokontrolera ESP32, firma Espressif, dostarcza bibliotekę do obsługi interfejsu I2C w ramach frameworku ESP-IDF.

W trakcie implementacji okazało się, że biblioteka ESP-IDF zawiera błąd w implementacji protokołu I2C, który uniemożliwiał poprawną komunikację z magnetometrem. Dodatkowo, bład ten był niewykrywalny w procesie debugowania, co nie pozwalało na jednoznaczne zlokalizowanie problemu (mógł wynikać z błędu w kodzie, konfiguracji, podłęczeniu lub z uszkodzenia magnetometru).

Błąd naprawiono poprzez zastosowanie alternatywnej biblioteki do obsługi interfejsu I2C, co pozwoliło na poprawną komunikację z magnetometrem.

## 7 Aplikacja mobilna

Aplikacja mobilna spełnia następujące funkcjonalności:
- rysowanie tras
- zapisywanie tras
- zarządzanie trasami
- nawiązywanie połączenia z urządzeniem SmartCompass
- przesyłanie tras do urządzenia SmartCompass

### 7.1 Wykorzystane technologie

Aplikacja została zrealizowana przy użyciu frameworku React Native [10] pozwalającego tworzyć jeden projekt, który następnie kompilowany jest do kodu aplikacji wykonywalnej na urządzeniach z Androidem jak i iOS. Ze względu na wymagania powiązane z uzyskaniem dostępu do modułu Bluetooth Low Energy urządzenia, zadecydowaliśmy się rozwijać naszą aplikację jedynie w kierunku systemu Android. Ponadto wykorzystano platformę i zestaw narzędzi Expo [6], które upraszczają proces tworzenia, testowania i wdrażania aplikacji mobilnych.

D. Cybulski, M. Durkalec, S. Kurzyp | Strona 9 z 16

### 7.2 Wykorzystane biblioteki

W aplikacji wykorzystano szereg bibliotek, które ułatwiły realizację poszczególnych funkcjonalności:
- react-native-async-storage - Służy do przechowywania danych lokalnych na urządzeniu. Umożliwia łatwe zapisywanie i odczytywanie danych, takich jak ustawienia użytkownika czy trasy.
- react-navigation - Biblioteka do nawigacji w aplikacjach React Native. Umożliwia łatwe zarządzanie stosami ekranów, nawigację pomiędzy nimi oraz implementację różnorodnych wzorców nawigacji.
- react-native-ble-plx - Biblioteka do obsługi Bluetooth Low Energy (BLE). Umożliwia skanowanie, łączenie i komunikację z urządzeniami BLE, co jest kluczowe dla integracji z urządzeniem SmartCompass.
- react-native-quick-base64 - Umożliwia szybkie kodowanie i dekodowanie danych w formacie base64, co jest przydatne przy przesyłaniu danych przez BLE.
- react-native-vector-icons - Biblioteka dostarczająca zestaw ikon do aplikacji. Umożliwia łatwe dodawanie ikon do przycisków, menu i innych elementów interfejsu użytkownika.
- react-native-maps - Biblioteka do integracji map w aplikacji. Umożliwia wyświetlanie map, rysowanie tras oraz interakcję z punktami na mapie.
- react-native-reanimated - Biblioteka do tworzenia płynnych i wydajnych animacji w aplikacji. Umożliwia tworzenie zaawansowanych animacji i interakcji, co poprawia ogólne wrażenia użytkownika.

### 7.3 Tworzenie wersji release aplikacji

Pierwszym krokiem jest dodanie informacji takich jak nazwa, ikona, splash screen oraz konfiguracje specyficzne dla platformy Android do pliku app.json.

Listing 4: Plik app.json
” expo ” : {
”name ” : ”app ” ,
” sl u g ” : ”app ” ,
” v e r s i o n ” : ” 1 . 0 . 0 ” ,
” o r i e n t a t i o n ” : ” p o r t r a i t ” ,
” i c o n ” : ”. / a s s e t s / i c o n . png ” , ” pl u gi n s ” : [
” r e a c t−n a ti v e−ble−pl x ”
] ,
” u s e r I n t e r f a c e S t y l e ” : ” l i g h t ” ,
” s pl a s h ” : {
”image ” : ”. / a s s e t s / s pl a s h . png ” , ” re sizeM ode ” : ” c o n t ai n ” ,
” backgroundColor ” : ”# f f f f f f ”
} ,
}

należy również utworzyć konfigurację dla usługi Expo Application Services (EAS), który jest częścią procesu budowania aplikacji. Konfigurację tą umieszcza się w pliku eas.json.

Listing 5: Plik eas.json
{
” c l i ” : {
” v e r s i o n ” : ”>= 8 . 0 . 0 ” } ,
” b uil d ” : {
” development ” : {
” d e v el o pm e n tCli e n t ” : t rue ,
D. Cybulski, M. Durkalec, S. Kurzyp | Strona 10 z 16

” d i s t r i b u t i o n ” : ” i n t e r n a l ” } ,
” p review ” : {
” and r oid ” : {
” buildType ” : ” apk ”
}
} ,
” p r o d u c ti o n ” : {}
} ,
” submit ” : {
” p r o d u c ti o n ” : {} }
} ;

Dla klucza preview określamy typ budowania aplikacji jako "apk" dla platformy Android. Następnie należy zalogować się do konta Expo, a później, korzystając z komendy ’npx build -p android {profile preview’, wygenerować plik .apk, który dostępny będzie do pobrania z konta użytkownika w platformie Expo. Proces generowania pliku .apk jest zautomatyzowany i przeprowadzany przez narzędzie Expo Build Service. W przypadku naszej aplikacji rozwiązanie to znacząco ułatwia cały proces względem Bare Workflow, czyli podejścia w którym nie wykorzystuje się frameworka Expo.

### 7.3.1 Różnice pomiędzy wersją testową, a release

Wersje testowe i release różnią się znacząco pod względem celu, konfiguracji, procesu budowania oraz dystrybucji. Wersje testowe są przeznaczone do szybkich iteracji i debugowania, zawierając narzędzia deweloperskie i umożliwiając natychmiastowe aktualizacje. Wersje release są zoptymalizowane pod kątem wydajności, stabilności i bezpieczeństwa, przeznaczone do dystrybucji do szerokiego grona użytkowników końcowych poprzez oficjalne sklepy aplikacji.

### 7.4 Napotkane problemy

Obsługa połączenia BLE z urządzeniem okazała się być trudniejsza niż zakładaliśmy, w szczególności monitorowanie sesji z poziomu aplikacji mobilnej. Cały proces wymaga również uzyskania odpowiednich pozwoleń od urządzenia na którym działa aplikacja, a proces testowania był utrudniony ponieważ posiadamy tylko jeden egzemplarz urządzenia SmartCompass. Ze względów technicznych UUID serwisu BLE naszego urządzenia SmartCompass został na sztywno ustawiony w aplikacji.

D. Cybulski, M. Durkalec, S. Kurzyp | Strona 11 z 16

## Część III

# Efekty

## 8 Prototyp urządzenia

Finalna wersja urządzenia została zmontowana na płytce prototypowej. (Rysunek 2) Z przodu urządzenia widoczny jest wyświetlacz LCD i ceramiczna antena modułu GPS, z tyłu znajdują się mikrokontrolej na płytce prototypowej, moduł GPS i moduł magnetometru. Prototyp korzysta z zasilania zewnętrznego poprzez kabel USB.

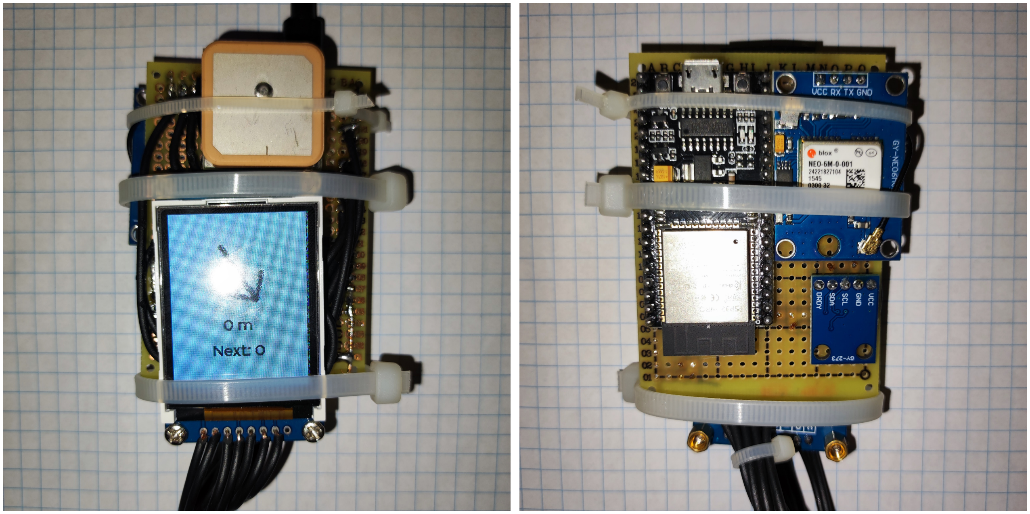
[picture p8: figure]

Rysunek 2: Prototyp urządzenia (widok z przodu i z tyłu)

### 8.1 Funkcjonalności

W aktualnej wersji urządzenie jest w stanie:
- Odczytywać dane z modułu GPS i magnetometru.
- Nawiązać połączenie w trybie BLE z aplikacją mobilną.
- Odbierać komendy od aplikacji mobilnej. (dane o nowej trasie)
- Wyświetlać na ekranie informacje o:

– Numerze następnego punktu na trasie

– Kierunku do następnego punktu

– Odległości do następnego punktu

– Zakończeniu nawigacji

D. Cybulski, M. Durkalec, S. Kurzyp | Strona 12 z 16

## 9 Aplikacja mobilna

### 9.1 Widoki aplikacji

### 9.1.1 BLE connection

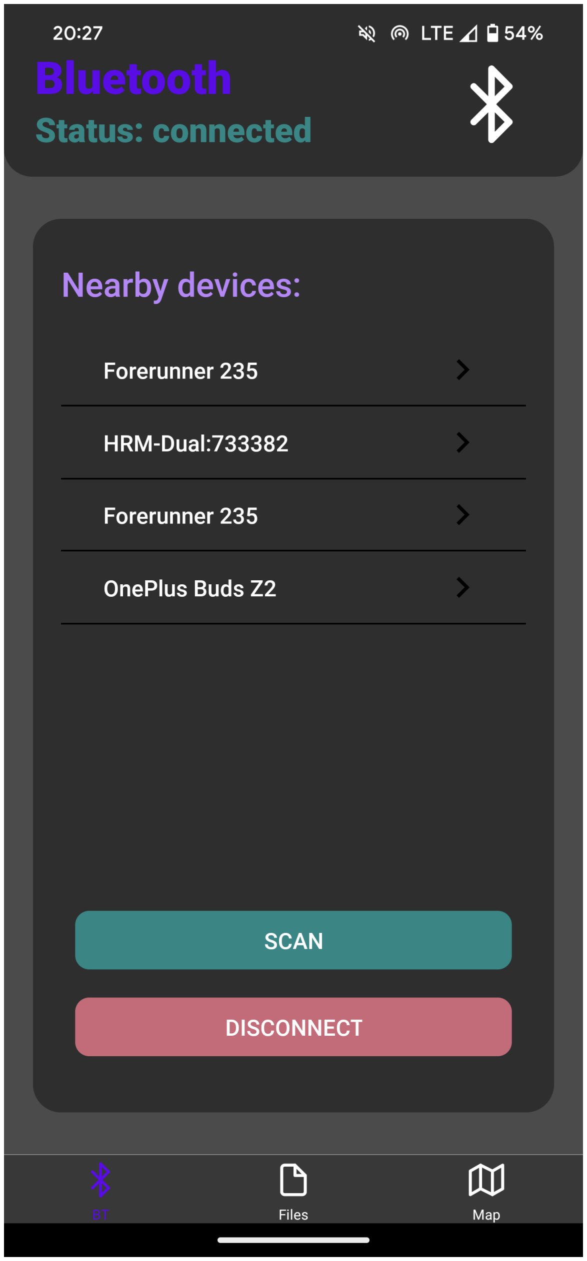
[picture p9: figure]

Rysunek 3: Ekran BLE connection

Widok ten pozwala użytkownikowi rozpocząć skanowanie pobliskich urządzeń BLE, a następnie wybrać jedno z nich i połączyć się z nim. Jeśli jest to urządzenie SmartCompass, to znaleziony zostanie udostępniany przez nie serwis BLE, którego UUID zapisane jest w aplikacji. Nawiązanie z nim połączenia umożliwi przesyłanie do tego urządzenia danych. Na ekranie tym znajdują się również dwa przyciski:
- Przycisk Scan - rozpoczyna skanowanie urządzeń
- Przycisk Disconnect - rozłącza z urządzeniem.

### 9.1.2 Files

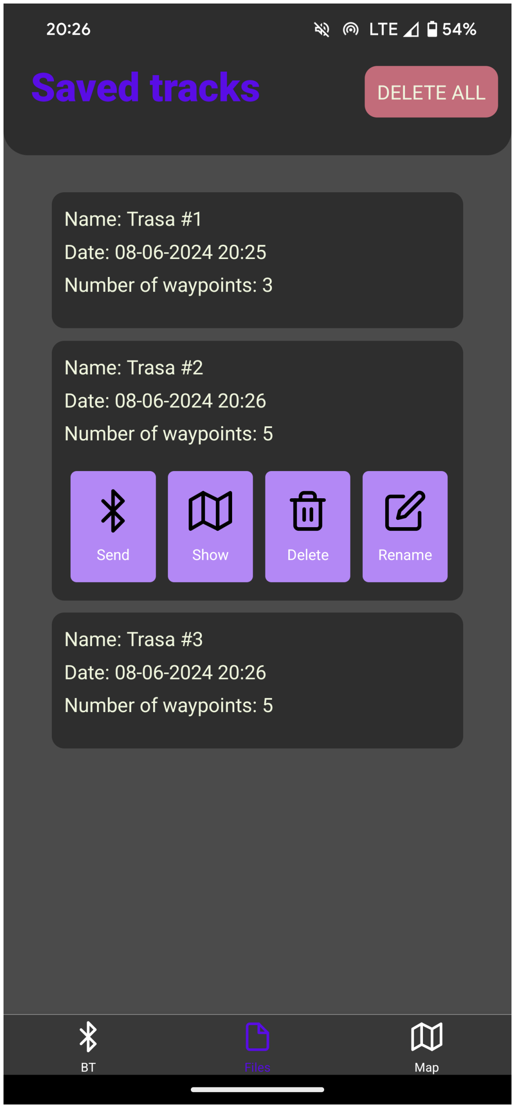
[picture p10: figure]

Rysunek 4: Ekran plików

D. Cybulski, M. Durkalec, S. Kurzyp | Strona 13 z 16

Widok ten oferuje możliwość przeglądania zapisanych w urządzeniu tras

Po kliknięciu w trasę, rozwinie się menu z 4 przyciskami:
- delete – usuwa wybraną trasę.
- edit – przenosi do widoku mapy i wyświetla w nim wybraną trasę pozwalając na jej edycję.
- send – pozwala przesłać wybraną trasę do urządzenia SmartCompass jeśli jest ono połączone.

### 9.1.3 Map

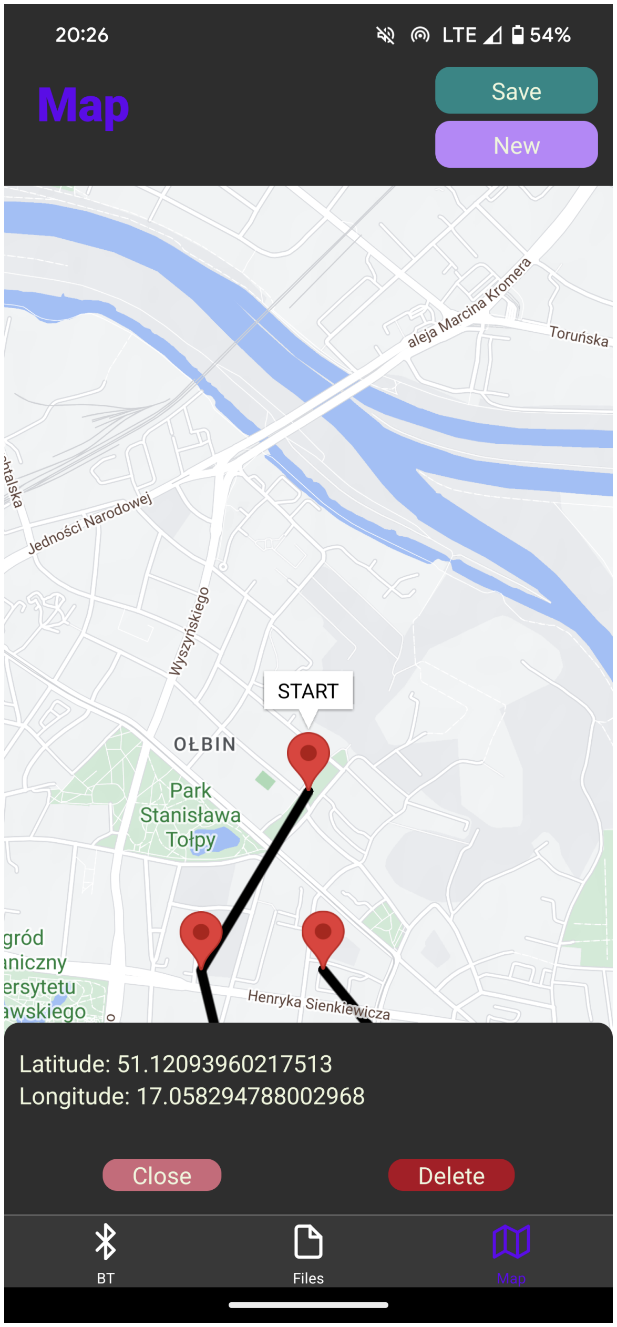
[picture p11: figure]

Rysunek 5: Ekran Mapy

Widok mapy oferuje możliwość rysowania trasy, dodawania nowej trasy oraz zapisu obecnie narysowanej trasy. W tym celu wykorzystywane są poniższe przyciski:
- NEW – wyczyszczenie punktów na mapie, jeśli trasa jest zapisana nie zostanie ona utracona. Pozwala na rysowanie nowej trasy
- SAVE – służy do zapisu aktualnie narysowanej trasy. Po kliknięciu pojawi się okienko z miejscem na wpisanie nazwy trasy. Trasa zapisana zostanie do wewnętrznej, statycznej pamięci urządzenia i widoczna będzie w widoku Files po restarcie aplikacji.

Ponadto do interakcji z mapą użytkownik wykorzystuje następujące gesty:
- przytrzymanie palcem w pustym miejscu na mapie – dodanie nowego punktu
- dłuższe przytrzymanie znacznika punktu – przejście w tryb przenoszenia punktu poprzez przesuwanie palcem po ekranie. Znacznik zostanie upuszczony po oderwaniu palca od ekranu
- kliknięcie w znacznik – nad znacznikiem wyświetli się małe pole z jego numerem na trasie lub napisem START/META. Ponadto na dole ekranu wyświetli się okno z dokładną lokalizacją punktu. Kliknięcie w puste miejsce na mapie spowoduje zamknięcie tego okna i zniknięcie pola nad znacznikiem.

## 10 Możliwości rozwoju

### 10.1 Rozwój urządzenia

W aktualnej wersji prototyp spełnia wszystkie wymagania prototypu funkcjonalnego, tzn. pozwala na:
- Weryfikacje komunikacji między wszystkimi komponentami.
D. Cybulski, M. Durkalec, S. Kurzyp | Strona 14 z 16

- Weryfikacje działania algorytmu nawigacji.
- Weryfikacje działania aplikacji mobilnej.
- Sprawdzenie trafności pomysłu na projekt. (Czy urządzenie w praktyce ma sens?)
- Szybką iterację nad projektem. (Wymiana modułów i sensorów bez dużych nakładów czasowych i finansowych)

Następnym krokiem w rozwoju urządzenia byłoby przygotowanie produktu do produkcji seryjnej. Wymagałoby to:
- Zaprojektowanie dedykowanego układu PCB, który zintegruje wszystkie komponenty i umożliwi miniaturyzacje urządzenia.
- Zaprojektowanie dedykowanego modułu zasilania, który będzie spełniał wymagania dotyczące czasu pracy urządzenia.
- Zaprojektowanie obudowy, która będzie spełniała wymagania wodoodporności i odporności na wstrząsy.

Dodatkowo, w celu zwiększenia atrakcyjności produktu można wprowadzić usprawnienia:
- W interfejsie użytkownika - dodanie dodatkowych informacji na wyświetlaczu, prezentacja informacji w bardziej atrakcyjny sposób.
- W stabilności działania - poprawa algorytmów nawigacji, zwiększenie dokładności pomiarów.
- W zużyciu energii - zastosowanie bardziej energooszczędnych komponentów, optymalizacja algorytmów.
- W funkcjonalności - dodanie dodatkowych funkcji, takich jak zapisywanie przebytej trasy, zapisywanie punktów zainteresowania, przechowywanie większej liczby tras.

### 10.2 Rozwój aplikacji mobilnej

Aplikacja realizuje zdefiniowane dla niej założenia. Potencjał na rozwój znajduje się w interfejsie użytkownika i, pomimo że jest kompletny, można wprowadzić zmiany, które poprawią ogólne wrażenia oraz intuicyjność korzystania z aplikacji dla użytkownika końcowego.

D. Cybulski, M. Durkalec, S. Kurzyp | Strona 15 z 16

## Literatura

[1] Amazon Web Services, Inc. Freertos documentation. https://freertos.org/index.html.
[2] Apache Software Foundation. Apache mynewt documentation. https://mynewt.apache.org/.
[3] Bluetooth SIG, Inc. | Bluetooth core specification 4.2. | https://www.bluetooth.com/
specifications/specs/core-specification-4-2/. (https://www.bluetooth.com/specifications/specs/core-specification-4-2/)
[4] Espressif Systems. | Esp-idf bluetooth nimble api reference. | https://docs.espressif.com/
projects/esp-idf/en/stable/esp32/api-reference/bluetooth/nimble/index.html. (https://docs.espressif.com/projects/esp-idf/en/stable/esp32/api-reference/bluetooth/nimble/index.html)
[5] Espressif Systems. Esp-idf getting started guide v5.2.1 (stable). https://docs.espressif.com/projects/esp-idf/en/stable/esp32/get-started/index.html. (https://docs.espressif.com/projects/esp-idf/en/stable/esp32/get-started/index.html)
[6] Expo Team. Expo documentation. https://expo.dev/.
[7] GitHub, | Inc. | About | projects. | https://docs.github.com/en/issues/
planning-and-tracking-with-projects/learning-about-projects/about-projects. (https://docs.github.com/en/issues/planning-and-tracking-with-projects/learning-about-projects/about-projects)
[8] LVGL Project. Lvgl esp32 drivers. https://github.com/lvgl/lvgl_esp32_drivers.
[9] LVGL Project. Lvgl esp32 port. https://github.com/lvgl/lv_port_esp32.
[10] Meta Platforms, Inc. React native documentation. https://reactnative.dev/.
D. Cybulski, M. Durkalec, S. Kurzyp | Strona 16 z 16

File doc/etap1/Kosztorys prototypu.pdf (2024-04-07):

# Kosztorys prototypu

Kosztorys uwzględnia tylko ceny głównych modułów urządzenia, dotychczasowe koszty zostały pokryte przez członków grupy projektowej.
Posiadamy inne niezbędne części podstawowe (rezystory, kondensatory, przyciski itp.), które będą niezbędne przy testowaniu prototypu.
Nazwa części | Typ | Przybliżona cena detaliczna | Faktyczny koszt
Espressif DevKitV4 ESP-WROOM-32E | DevKit z Mikrokontrolerem | 35,99 zł | 35,99 zł
GY-273 | Magnetometr cyfrowy 3-osiowy | 17,00 zł | 13,71 zł
GY-NEO6MV2 | Moduł GPS z anteną | 27,99 zł | 27,99 zł
Waveshare 13892 | Wyświetlacz LCD 128x160px | 33,90 zł | 0,00 zł
| | 114,88 zł | 77,69 zł

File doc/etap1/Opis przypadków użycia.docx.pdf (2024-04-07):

Opis przypadków użycia

Planowanie trasy: Aplikacja umożliwia planowanie trasy, które polega na dodawaniu po kolei punktów z których zostanie ona utworzona. Użytkownik ma również możliwość usuwania lub przesuwania wybranych punktów. Zakończenie planowania trasy wiąże się z zapisaniem jej do pamięci urządzenia mobilnego lub odrzuceniem.

Przeglądanie zapisanych tras: trasy zapisane są w urządzeniu mobilnym. Użytkownik może przeglądać je oraz usuwać.

Konfiguracja połączenia Bluetooth: Aplikacja umożliwia konfigurację połączenia pomiędzy urządzeniem mobilnym, a urządzeniem Smart-Compass

Konfiguracja urządzenia Smart-Compass: Aplikacja umożliwia konfigurację urządzenia Smart-Compass

Przesyłanie trasy na urządzenie: Aplikacja umożliwia przesyłanie trasy na urządzenie Smart-Compass. Wymaga to wcześniejszego przetworzenia go na format GPX.

Opis widoków aplikacji

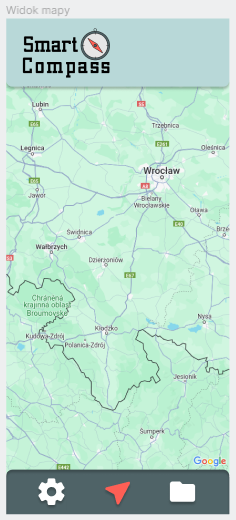
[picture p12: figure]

Widok mapy

W widoku mapy użytkownik może swobodnie przeglądać mapę oraz przełączać się do widoku ustawień lub zapisanych tras w ramach paska nawigacji na dole. Przytrzymanie palcem na ekranie spowoduje dodanie punktu i przejście od widoku dodawania punktów.

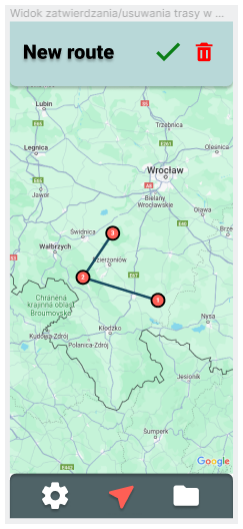
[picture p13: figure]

Widok zatwierdzania trasy

W widoku tym użytkownik może przeglądać zaplanowaną trasę, wchodzić w interakcję z poszczególnymi punktami poprzez kliknięcie i przejście do widoku dodawania punktu lub dodawać nowe punkty poprzez przytrzymanie palcem miejsca na ekranie. Ponadto może zapisać lub odrzucić trasę.

Ma również dostęp do paska nawigacji i powiązanych z nim funkcjonalności.

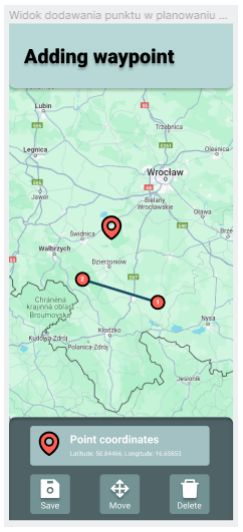
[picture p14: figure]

Widok dodawania punktu

W tym widoku użytkownik może wykonywać akcję dotyczące dodanego punktu takie jak: zapisanie go i przejście do widoku zatwierdzanie trasy, przemieszczenie w inne miejsce, usunięcie i przejście do widoku zatwierdzanie trasy.

Ma również dostęp do paska nawigacji i powiązanych z nim funkcjonalności.

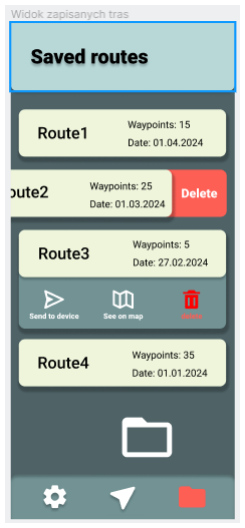
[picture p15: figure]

Widok zapisanych tras

Widok ten pozwala na przeglądanie zapisanych lokalnie na urządzeniu tras. Ponadto daje możliwość wyświetlania trasy na mapie – przeniesienie do widoku zatwierdzania tras, wysłania trasy do urządzenia Smart Compass – przenosi do widoku Konfiguracja połączenia Bluetooth jeśli połączenie nie jest skonfigurowane oraz pozwala na usunięcie trasy.

Ma również dostęp do paska nawigacji i powiązanych z nim funkcjonalności.

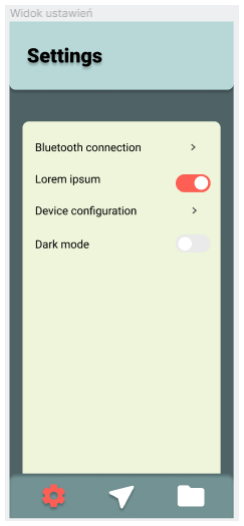
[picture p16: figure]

Widok ustawień

Widok ustawień pozwala na przeglądanie dostępnych opcji i przechodzenie do odpowiadających im widoków

Ma również dostęp do paska nawigacji i powiązanych z nim funkcjonalności.

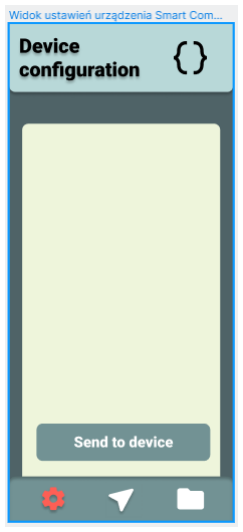
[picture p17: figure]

Widok konfiguracji ustawień urządzenia

Widok pozwala na stworzenie pliku konfiguracyjnego dla urządzenia Smart Compass i przesłanie go. Jeśli połączenie nie jest skonfigurowane nastąpi przeniesienie do widoku Konfiguracja połączenia Bluetooth.

Ma również dostęp do paska nawigacji i powiązanych z nim funkcjonalności.

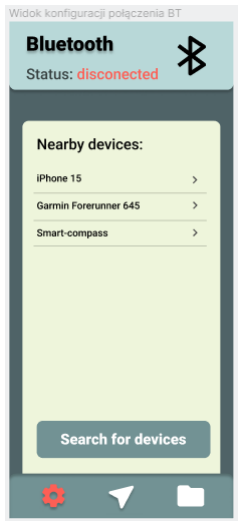
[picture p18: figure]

Widok konfiguracji połączenia BlueTooth

Widok ten pozwala na wyszukiwania urządzeń BT w otoczeniu, a następnie wybór jednego z nich i nawiązania z nim połączenia.

Ma również dostęp do paska nawigacji i powiązanych z nim funkcjonalności.

Wybrane technologie i biblioteki

React Native expo - do zaprojektowania aplikacji zostanie wykorzystany framework React Native oraz Expo. Rozwiązanie to pozwala tworzyć jedną aplikację działająca zarówno na urządzeniach z Androidem jak i iOS.

react-native-maps - jest to biblioteka wykorzystująca API Google maps. Dostarcza komponenty potrzebne do umieszczenia w aplikacji mapy oraz dodawania punktów i rysowania prostych.

react-native-ble-manager - biblioteka służąca do komunikacji z systemowymi API w celu konfiguracji połączenia Bluetooth Low Energy.

gpx-builder - biblioteka do tworzenia plików GPX

Async storage – interface zostanie wykorzystany do przechowywania danych w pamięci urządzenia mobilnego. Funkcjonalność ta potrzebna jest do zapisywania tras utworzonych przez użytkownika oraz przechowywania pliku konfiguracyjnego urządzenia Smart Compass.

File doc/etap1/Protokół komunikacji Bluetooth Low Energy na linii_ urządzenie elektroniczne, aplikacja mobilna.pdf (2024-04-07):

# Protokół komunikacji Bluetooth Low Energy na

linii: urządzenie elektroniczne, aplikacja mobilna.

Standard: Bluetooth Core 4.2, (https://www.bluetooth.com/specifications/specs/core-specification-4-2/) Rozdział 4.4 Low Energy Core Configuration
Standard zaimplementowany na ESP32, jest kompatybilny z nowszymi wersjami BL.

## Obsługa komunikacja po stronie urządzenia elektronicznego

- Dostępne stosy Bluetooth dla ESP32 (https://docs.espressif.com/projects/esp-idf/en/latest/esp32/api-guides/bluetooth.html)
ESP-Bluedroid (https://docs.espressif.com/projects/esp-idf/en/latest/esp32/api-guides/bluetooth.html#esp-bluedroid) | ● Pełna implementacja stosu Bluetooth ● Duże zużycie pamięci podręcznej i flash
ESP-NimBLE (https://docs.espressif.com/projects/esp-idf/en/latest/esp32/api-guides/bluetooth.html#esp-nimble) | ● Implementacja tylko Bluetooth LE ● Małe zużycie pamięci podręcznej i flash

## Obsługa komunikacji po stronie aplikacji mobilnej

- Biblioteka Bluetooth LE dla React Native (https://github.com/innoveit/react-native-ble-manager)
- Wersja standardu BLE zależna od urządzenia mobilnego.
- Wsparcie dla Android (API 19+) i iOS 10+

## Obsługa połączenia Bluetooth

Jest implementowana na podstawie standardu Bluetooth Core 4.2, kompas implementuje podstawową listę atrybutów (GATT), co pozwala na wykrycie i połączenie przez dowolne urządzenie mobilne.

## Deklaracja Serwisu i Charakterystyki GAP

Na podstawie standardu Bluetooth Core 4.2, Część G, Sekcja 3.1

### Deklaracja Serwisu podstawowego

Serwis podstawowy jest główną składową profilu GATT i pozwala na jednoznaczną definicję niezbędnych zapytań do serwera Bluetooth (w tym przypadku jest to kompas)

Attribute Handle | Attribute Type | Attribute Value (Service UUID)
0x0001 | 0x2800 (primary service) | 0x0000…0001 (128b)

### Deklaracja Charakterystyki odpowiedzialnej za przechowywanie trasy

Charakterystyki GATT pozwalają na zdefiniowanie struktury par klucz - wartość, wraz z odpowiednimi uprawnieniami dostępu.

Attribute Handle | Attribute Type | Attribute Value (Characteristic UUID)
0x0002 | 0x2803 (Characteristic) | 0x0000…0002 (128b)

Dodatkowe pola deklaracji charakterystyki:

Attribute Value | Size | Value
Characteristic Properties | 1 octets | 0x0A (Read & Write)
Characteristic Value Handle | 2 octets | 0x0003 (Wskaźnik na atrybut, w którym przechowywane są dane trasy)

Dodatkowe deklaracje atrybutów GATT mogą być niezbędne po stronie serwera BLE (kompas), w celu poprawnej komunikacji z klientem; zdefiniowane wyżej atrybuty są niezbędną fasadą do implementacji komunikacji po stronie aplikacji mobilnej.

## Przesyłanie nowej trasy do urządzenia

Trasa o długości N jest przesyłana i przechowywana jako tablica par typu float (32 bit).

lat_0 | lon_0 | lat_1 | lon_1 | … | lon_N
- Cała tablica ma rozmiar 2*N*4b = N* 8b
- Przesłanie nowej tablicy jest równoznaczne z rozpoczęciem nawigacji po nowej trasie.
Przesyłanie trasy odbywa się przez wysłanie zapytania BLE typu Characteristic Value Write dla deskryptora o adresie 0x0002 (Characteristic UUID).

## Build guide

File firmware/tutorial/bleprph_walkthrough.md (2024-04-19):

# BLE Peripheral Example Walkthrough

## Introduction

In this tutorial, the ble peripheral example code for the espressif chipsets is reviewed. This example aims at understanding GATT database configuration, handling GATT reads and writes, handling subscribe events, and understanding advertisement and SMP-related NimBLE APIs.It also demonstrates the security features of the NimBLE stack. SMP parameters like I/O capabilities of the device, Bonding flag, MITM protection flag and Secure Connection only mode, Enabling Link Encryption, etc., can be configured through menuconfig options.

## Includes

This example is located in the examples folder of the ESP-IDF under the [bleprph/main](../main). The [main.c](../main/main.c) file located in the main folder contains all the functionality that we are going to review. The header files contained in [main.c](../main/main.c) are:
These `includes` are required for the FreeRTOS and underlying system components to run, including the logging functionality and a library to store data in non-volatile flash memory. We are interested in `“nimble_port.h”`, `“nimble_port_freertos.h”`, `"ble_hs.h"` and `“ble_svc_gap.h”`, `“bleprph.h”` which expose the BLE APIs required to implement this example.

* `nimble_port.h`: Includes the declaration of functions required for the initialization of the nimble stack.
* `nimble_port_freertos.h`: Initializes and enables nimble host task.
* `ble_hs`.h`: Defines the functionalities to handle the host event
* `ble_svc_gap`.h`: Defines the macros for device name, and device appearance and declares the function to set them.
* `bleprph.h`: It includes the code containing forward declarations of 2 structs `ble_hs_cfg`, and `ble_gatt_register_ctxt`. It also defines the UUIDs for gatt server services and characteristics.

## Main Entry Point

The program’s entry point is the app_main() function:

```c
void
app_main(void)
{
    int rc;

    /* Initialize NVS — it is used to store PHY calibration data */
    esp_err_t ret = nvs_flash_init();
    if (ret == ESP_ERR_NVS_NO_FREE_PAGES || ret == ESP_ERR_NVS_NEW_VERSION_FOUND) {
        ESP_ERROR_CHECK(nvs_flash_erase());
        ret = nvs_flash_init();
    }
    ESP_ERROR_CHECK(ret);

    ret = nimble_port_init();
    if (ret != ESP_OK) {
        ESP_LOGE(tag, "Failed to init nimble %d ", ret);
        return;
    }
    /* Initialize the NimBLE host configuration. */
    ble_hs_cfg.reset_cb = bleprph_on_reset;
    ble_hs_cfg.sync_cb = bleprph_on_sync;
    ble_hs_cfg.gatts_register_cb = gatt_svr_register_cb;
    ble_hs_cfg.store_status_cb = ble_store_util_status_rr;

    ble_hs_cfg.sm_io_cap = CONFIG_EXAMPLE_IO_TYPE;
#ifdef CONFIG_EXAMPLE_BONDING
    ble_hs_cfg.sm_bonding = 1;
    /* Enable the appropriate bit masks to make sure the keys
     * that are needed are exchanged
     */
    ble_hs_cfg.sm_our_key_dist |= BLE_SM_PAIR_KEY_DIST_ENC;
    ble_hs_cfg.sm_their_key_dist |= BLE_SM_PAIR_KEY_DIST_ENC;
#endif
#ifdef CONFIG_EXAMPLE_MITM
    ble_hs_cfg.sm_mitm = 1;
#endif
#ifdef CONFIG_EXAMPLE_USE_SC
    ble_hs_cfg.sm_sc = 1;
#else
    ble_hs_cfg.sm_sc = 0;
#endif
#ifdef CONFIG_EXAMPLE_RESOLVE_PEER_ADDR
    /* Stores the IRK */
    ble_hs_cfg.sm_our_key_dist |= BLE_SM_PAIR_KEY_DIST_ID;
    ble_hs_cfg.sm_their_key_dist |= BLE_SM_PAIR_KEY_DIST_ID;
#endif

    rc = gatt_svr_init();
    assert(rc == 0);

    /* Set the default device name. */
    rc = ble_svc_gap_device_name_set("nimble-bleprph");
    assert(rc == 0);

    /* XXX Need to have template for store */
    ble_store_config_init();

    nimble_port_freertos_init(bleprph_host_task);

    /* Initialize command line interface to accept input from user */
    rc = scli_init();
    if (rc != ESP_OK) {
        ESP_LOGE(tag, "scli_init() failed");
    }
}
```
The main function starts by initializing the non-volatile storage library. This library allows us to save the key-value pairs in flash memory.`nvs_flash_init()` stores the PHY calibration data. In a Bluetooth Low Energy (BLE) device, cryptographic keys used for encryption and authentication are often stored in Non-Volatile Storage (NVS).BLE stores the peer keys, CCCD keys, peer records, etc on NVS. By storing these keys in NVS, the BLE device can quickly retrieve them when needed, without the need for time-consuming key generations.
```c
esp_err_t ret = nvs_flash_init();
if (ret == ESP_ERR_NVS_NO_FREE_PAGES || ret == ESP_ERR_NVS_NEW_VERSION_FOUND) {
    ESP_ERROR_CHECK(nvs_flash_erase());
    ret = nvs_flash_init();
}
ESP_ERROR_CHECK( ret );
```
## BT Controller and Stack Initialization

The main function calls `nimble_port_init()` to initialize BT Controller and nimble stack. This function initializes the BT controller by first creating its configuration structure named `esp_bt_controller_config_t` with default settings generated by the `BT_CONTROLLER_INIT_CONFIG_DEFAULT()` macro. It implements the Host Controller Interface (HCI) on the controller side, the Link Layer (LL), and the Physical Layer (PHY). The BT Controller is invisible to the user applications and deals with the lower layers of the BLE stack. The controller configuration includes setting the BT controller stack size, priority, and HCI baud rate. With the settings created, the BT controller is initialized and enabled with the `esp_bt_controller_init()` and `esp_bt_controller_enable()` functions:

```c
esp_bt_controller_config_t config_opts = BT_CONTROLLER_INIT_CONFIG_DEFAULT();
ret = esp_bt_controller_init(&config_opts);
```
Next, the controller is enabled in BLE Mode.

```c
ret = esp_bt_controller_enable(ESP_BT_MODE_BLE);
```
The controller should be enabled in `ESP_BT_MODE_BLE` if you want to use the BLE mode.

There are four Bluetooth modes supported:

1. `ESP_BT_MODE_IDLE`: Bluetooth not running
2. `ESP_BT_MODE_BLE`: BLE mode
3. `ESP_BT_MODE_CLASSIC_BT`: BT Classic mode
4. `ESP_BT_MODE_BTDM`: Dual mode (BLE + BT Classic)

After the initialization of the BT controller, the nimble stack, which includes the common definitions and APIs for BLE, is initialized by using `esp_nimble_init()`:

```c
esp_err_t esp_nimble_init(void)
{

#if !SOC_ESP_NIMBLE_CONTROLLER
    /* Initialize the function pointers for OS porting */
    npl_freertos_funcs_init();

    npl_freertos_mempool_init();

    if(esp_nimble_hci_init() != ESP_OK) {
        ESP_LOGE(NIMBLE_PORT_LOG_TAG, "hci inits failed\n");
        return ESP_FAIL;
    }

    /* Initialize default event queue */
    ble_npl_eventq_init(&g_eventq_dflt);

    os_msys_init();

    void ble_store_ram_init(void);
    /* XXX Need to have a template for store */
    ble_store_ram_init();
#endif

    /* Initialize the host */
    ble_hs_init();
    return ESP_OK;
}
```

The host is configured by setting up the callbacks that get executed upon  Stack-reset, Stack-sync, registration of each GATT resource (service, characteristic, or descriptor), and when a persistence operation cannot be performed or a persistence failure is imminent.

```c
ble_hs_cfg.reset_cb = bleprph_on_reset;
ble_hs_cfg.sync_cb = bleprph_on_sync;
ble_hs_cfg.gatts_register_cb = gatt_svr_register_cb;
ble_hs_cfg.store_status_cb = ble_store_util_status_rr;
```

## Security Manager Configuration
Security Manager (sm_ members) is configurable at runtime to simplify security testing. Defaults for those are configured by selecting proper options via menuconfig for example configurations.

### I/O CAPABILITIES
```c
ble_hs_cfg.sm_io_cap = CONFIG_EXAMPLE_IO_TYPE; // Security Manager Local Input Output Capabilities is set to 3 which represents no input and no output.
```
### USE BONDING 
```c
#ifdef CONFIG_EXAMPLE_BONDING
    ble_hs_cfg.sm_bonding = 1; // If set proper flag in Pairing, Request/Response will be set. This results in storing keys distributed during bonding

    /* Enable the appropriate bit masks to make sure the keys
     * that are needed are exchanged
     */
    ble_hs_cfg.sm_our_key_dist |= BLE_SM_PAIR_KEY_DIST_ENC; // Security Manager Local Key Distribution Mask

    ble_hs_cfg.sm_their_key_dist |= BLE_SM_PAIR_KEY_DIST_ENC; //Security Manager Remote Key Distribution Mask 
#endif
```
`CONFIG_EXAMPLE_BONDING` is set to enable the bonding on Bleprph. By default this flag is disabled. It can be configured through the sdkconfig file or from the menuconfig options.
The Following are screenshots of the same.

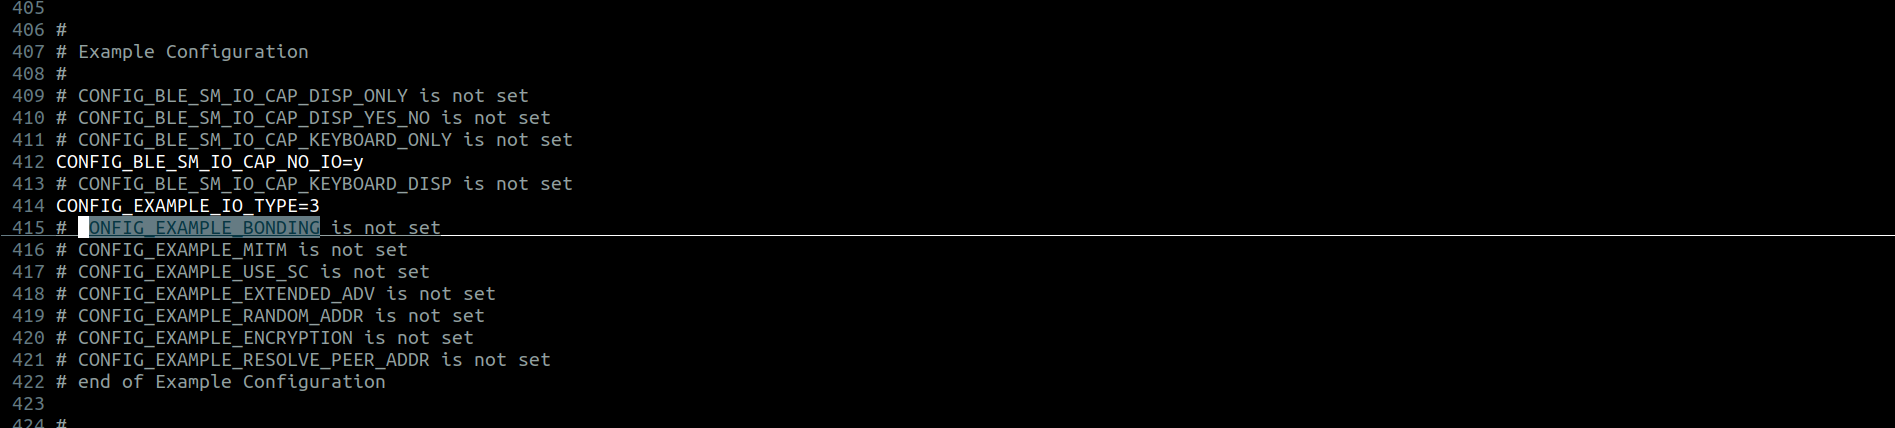
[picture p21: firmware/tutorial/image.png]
SDKCONFIG


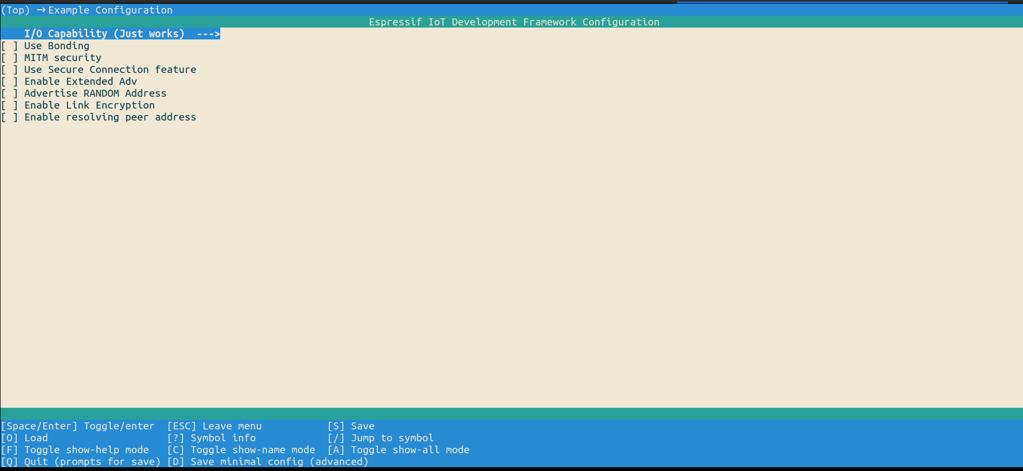
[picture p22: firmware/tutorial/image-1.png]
MENUCONFIG


### MITM PROTECTION
```c
#ifdef CONFIG_EXAMPLE_MITM
    ble_hs_cfg.sm_mitm = 1; 
#endif
```
When the `CONFIG_EXAMPLE_MITM` flag is set during pairing, it will enable the MITM bit in the auth req field of pairing request, which in turn necessitates protection against Man-In-The-Middle attacks during the pairing process. The flag can be configured through sdkconfig or menuconfig as mentioned above.

### SECURE CONNECTION FEUTURE
```c
#ifdef CONFIG_EXAMPLE_USE_SC
    ble_hs_cfg.sm_sc = 1;
#else
    ble_hs_cfg.sm_sc = 0;
#endif
```
When the `CONFIG_EXAMPLE_USE_SC` flag is set in the Pairing Request/Response, it enables the usage of LE Secure Connections for pairing, provided that the remote device also supports it. If the remote device does not support LE Secure Connections, the pairing process falls back to using legacy pairing.

### ENABLE RESOLVING PEER ADDRESS
```c
#ifdef CONFIG_EXAMPLE_RESOLVE_PEER_ADDR
    /* Stores the IRK */
    ble_hs_cfg.sm_our_key_dist |= BLE_SM_PAIR_KEY_DIST_ID;
    ble_hs_cfg.sm_their_key_dist |= BLE_SM_PAIR_KEY_DIST_ID;
#endif
```
Above snippet is representing the distribution of identity resolving keys (IRKs) during the pairing process. IRKs are used in Bluetooth's device address resolution process, which allows devices to associate a resolvable private address with a public identity (IRK). This enhances privacy by making it difficult to track a device solely based on its address. This sets the keys that are distributed during the phase 3 for SMP pairing.

## GATT SERVER INIT
```c
 rc = gatt_svr_init();
    assert(rc == 0);
```
The gatt_svr_init function is called during the initialization phase of a BLE application to set up the GATT server and define the services and characteristics it supports. 

## SETTING DEVICE NAME
The main function calls `ble_svc_gap_device_name_set()` to set the default device name. 'nimble-bleprph' is passed as the default device name to this function.
```c
rc = ble_svc_gap_device_name_set("nimble-bleprph");
```
## BLE STORE CONFIGURATION
main function calls  `ble_store_config_init()` to configure the host by setting up the storage callbacks which handle the read, write, and deletion of security material.
```c
/* XXX Need to have a template for store */
    ble_store_config_init();
```
## THREAD MODEL
The main function creates a task where nimble will run using `nimble_port_freertos_init()`. This enables the nimble stack by using `esp_nimble_enable()`. 
```c
nimble_port_freertos_init(bleprph_host_task);
```
`esp_nimble_enable()` create a task where the nimble host will run. Nimble stack runs in a separate thread with its own context to handle async operations from controller and post HCI commands to controller.

## SETTING COMMAND-LINE INTERFACE
```c
  rc = scli_init();
    if (rc != ESP_OK) {
        ESP_LOGE(tag, "scli_init() failed");
    }
```
To initialize a command line interface (CLI) that accepts input from the user, the function scli_init() is used. This function registers the CLI command "key <value>" to receive input from the user during the pairing process. The pairing process is facilitated using the ble_register_cli() function.

# PERIPHERAL ADVERTISEMENT

1. Peripheral advertisement is used by many applications to start advertising from applications.`bleprph` example provides this feature of advertisement. It uses the following function to start an advertisement.
2. `bleprph_advertise` start by creating the instances of structures `ble_gap_adv_params` and `ble_hs_adv_fields`.
3. Advertising parameters such as connecting modes, discoverable modes, advertising intervals, channel map advertising filter policy, and high duty cycle for directed advertising are defined in these structures.
4. `ble_hs_adv_fields` provides a structure to store advertisement data in a Bluetooth Low Energy (BLE) application. It contains various data members, such as flags (indicating advertisement type and other general information), advertising transmit power, device name, and 16-bit service UUIDs (such as alert notifications), etc.

Below is the implementation to start the advertisement.
```c
static void
bleprph_advertise(void)
{
    struct ble_gap_adv_params adv_params;
    struct ble_hs_adv_fields fields;
    const char *name;
    int rc;

    /**
     *  Set the advertisement data included in our advertisements:
     *     o Flags (indicates advertisement type and other general info).
     *     o Advertising tx power.
     *     o Device name.
     *     o 16-bit service UUIDs (alert notifications).
     */

    memset(&fields, 0, sizeof fields);

    /* Advertise two flags:
     *     o Discoverability in forthcoming advertisement (general)
     *     o BLE-only (BR/EDR unsupported).
     */
    fields.flags = BLE_HS_ADV_F_DISC_GEN |
                   BLE_HS_ADV_F_BREDR_UNSUP;

    /* Indicate that the TX power level field should be included; have the
     * stack fill this value automatically.  This is done by assigning the
     * special value BLE_HS_ADV_TX_PWR_LVL_AUTO.
     */
    fields.tx_pwr_lvl_is_present = 1;
    fields.tx_pwr_lvl = BLE_HS_ADV_TX_PWR_LVL_AUTO;

    name = ble_svc_gap_device_name();
    fields.name = (uint8_t *)name;
    fields.name_len = strlen(name);
    fields.name_is_complete = 1;

    fields.uuids16 = (ble_uuid16_t[]) {
        BLE_UUID16_INIT(GATT_SVR_SVC_ALERT_UUID)
    };
    fields.num_uuids16 = 1;
    fields.uuids16_is_complete = 1;

    rc = ble_gap_adv_set_fields(&fields);
    if (rc != 0) {
        MODLOG_DFLT(ERROR, "error setting advertisement data; rc=%d\n", rc);
        return;
    }

    /* Begin advertising. */
    memset(&adv_params, 0, sizeof adv_params);
    adv_params.conn_mode = BLE_GAP_CONN_MODE_UND;
    adv_params.disc_mode = BLE_GAP_DISC_MODE_GEN;
    rc = ble_gap_adv_start(own_addr_type, NULL, BLE_HS_FOREVER,
                           &adv_params, bleprph_gap_event, NULL);
    if (rc != 0) {
        MODLOG_DFLT(ERROR, "error enabling advertisement; rc=%d\n", rc);
        return;
    }
}
```
## Configuration of Advertising data(`ble_hs_adv_fields fields`) 

### Setting advertising flags and transmitting power level
```c
  memset(&fields, 0, sizeof fields);

    fields.flags = BLE_HS_ADV_F_DISC_GEN |
                   BLE_HS_ADV_F_BREDR_UNSUP;
    fields.tx_pwr_lvl_is_present = 1;
    fields.tx_pwr_lvl = BLE_HS_ADV_TX_PWR_LVL_AUTO;
```
All data members of `fields` are initialized to 0 before setting up using the `memset()` function. Discoverability for upcoming advertisements is set to general. Advertisement is set to BLE supported only. Assigning the `tx_pwr_lvl` field to `BLE_HS_ADV_TX_PWR_LVL_AUTO` prompts the stack to automatically fill in the transmit power level field.

### Setting up the device name
```c
    name = ble_svc_gap_device_name();
    fields.name = (uint8_t *)name;
    fields.name_len = strlen(name);
    fields.name_is_complete = 1;
```
The app main function call the API `ble_svc_gap_device_name_set("nimble-bleprph")` which takes the user defined device name as a parameter. This API sets the device name to the characters array `ble_svc_gap_name` defined in the file [ble_svc_gap.c](../../../../../components/bt/host/nimble/nimble/nimble/host/services/gap/src/ble_svc_gap.c). The `ble_svc_gap_device_name()` API returns the same above mentioned char array which was set from the main function.

### Setting up the UUID for alert notification
```c
    fields.uuids16 = (ble_uuid16_t[]) {
        BLE_UUID16_INIT(GATT_SVR_SVC_ALERT_UUID)
    };
    fields.num_uuids16 = 1;
    fields.uuids16_is_complete = 1;

    rc = ble_gap_adv_set_fields(&fields);
    if (rc != 0) {
        MODLOG_DFLT(ERROR, "error setting advertisement data; rc=%d\n", rc);
        return;
    }
```
This example uses ANS service just as a way to uniquely identify itself from multiple advertisers and client can find it to connect to.
`ble_gap_adv_set_fields()` sets the following advertising data. This API internally depends on other APIs to set the data.APIs can be checked here [ble_hs_adv.c](../../../../../components/bt/host/nimble/nimble/nimble/host/src/ble_hs_adv.c)
1. Adv flags   
2. 16-bit service class UUIDS
3. 32-bit service class UUIDS
4. 128-bit service class UUIDS
5. Local Name
6. Tx Power Level
7. Slave connection interval range
8. Service data - 16-bit UUID
9. Public target address
10. Appearance
11. Advertising interval
12. Service data - 32-bit UUID
13. Service data - 128-bit UUID
14. URI
15. Manufacturer-specific data

## Start Advertisement

```c
memset(&adv_params, 0, sizeof adv_params);
    adv_params.conn_mode = BLE_GAP_CONN_MODE_UND;
    adv_params.disc_mode = BLE_GAP_DISC_MODE_GEN;
    rc = ble_gap_adv_start(own_addr_type, NULL, BLE_HS_FOREVER,
                           &adv_params, bleprph_gap_event, NULL);
    if (rc != 0) {
        MODLOG_DFLT(ERROR, "error enabling advertisement; rc=%d\n", rc);
        return;
    }
```
Advertisement parameters are initialized to 0 using `memset`. Enables advertising with general discoverable mode and undirected connectable mode.
The `ble_gap_adv_start()` function configures and starts the advertising procedure.

The description of the `ble_gap_adv_start()` method is as follows:
```c
Return Value : 0 on success, error code on failure
```

```c
Parameters

1. `own_addr_type`:The type of address the stack should use for itself. Valid values are:
- BLE_OWN_ADDR_PUBLIC
- BLE_OWN_ADDR_RANDOM
- BLE_OWN_ADDR_RPA_PUBLIC_DEFAULT
- BLE_OWN_ADDR_RPA_RANDOM_DEFAULT
2. `direct_addr`:The peer’s address for directed advertising. This parameter shall be non-NULL if directed advertising is being used. In this case, we have set it to NULL.
3. `duration_ms`: The duration of the advertisement procedure. On expiration, the procedure ends and a BLE_GAP_EVENT_ADV_COMPLETE event is reported. Units are milliseconds. Specify BLE_HS_FOREVER for no expiration.
4. `adv_params`: Additional arguments specifying the particulars of the advertising procedure.
5. `cb`: The callback to associate with this advertising procedure. If advertising ends, the event is reported through this callback. If advertising results in a connection, the connection inherits this callback as its event-reporting mechanism. The Callback, in this case, is `bleprph_gap_event`.
6. `cb_arg `: The optional argument to pass to the callback function.
```
## Extended Advertisement

```c
static void
ext_bleprph_advertise(void)
{
    struct ble_gap_ext_adv_params params;
    struct os_mbuf *data;
    uint8_t instance = 0;
    int rc;

    /* First check if any instance is already active */
    if(ble_gap_ext_adv_active(instance)) {
        return;
    }

    /* use defaults for non-set params */
    memset (&params, 0, sizeof(params));

    /* enable connectable advertising */
    params.connectable = 1;

    /* advertise using random addr */
    params.own_addr_type = BLE_OWN_ADDR_PUBLIC;

    params.primary_phy = BLE_HCI_LE_PHY_1M;
    params.secondary_phy = BLE_HCI_LE_PHY_2M;
    //params.tx_power = 127;
    params.sid = 1;

    params.itvl_min = BLE_GAP_ADV_FAST_INTERVAL1_MIN;
    params.itvl_max = BLE_GAP_ADV_FAST_INTERVAL1_MIN;

    /* configure instance 0 */
    rc = ble_gap_ext_adv_configure(instance, &params, NULL,
                                   bleprph_gap_event, NULL);
    assert (rc == 0);

    /* in this case only scan response is allowed */

    /* get mbuf for scan rsp data */
    data = os_msys_get_pkthdr(sizeof(ext_adv_pattern_1), 0);
    assert(data);

    /* fill mbuf with scan rsp data */
    rc = os_mbuf_append(data, ext_adv_pattern_1, sizeof(ext_adv_pattern_1));
    assert(rc == 0);

    rc = ble_gap_ext_adv_set_data(instance, data);
    assert (rc == 0);

    /* start advertising */
    rc = ble_gap_ext_adv_start(instance, 0, 0);
    assert (rc == 0);
}
```
Structure Declarations: The code declares structures and variables required for configuring and starting extended advertising.

1. Check for Active Instance: It checks whether the advertising instance with the specified instance number (0 in this case) is already active. If it's active, the function returns, meaning no further action is taken.

2. Initialize Advertising Parameters: The params structure is initialized with advertising parameters. It specifies that the advertising will be connectable, using a public address, with specified PHYs, set advertising set ID, and interval values.

3. Configure Advertising Instance: The function ble_gap_ext_adv_configure is called to configure the advertising instance with the specified parameters. It also associates a callback function bleprph_gap_event for handling GAP (Generic Access Profile) events related to advertising.

4. Allocate Memory for Scan Response Data: Memory is allocated to store scan response data using the function os_msys_get_pkthdr. The size of memory allocated is based on the size of ext_adv_pattern_1.

5. Fill Scan Response Data: The scan response data is filled into the allocated memory using os_mbuf_append. This data will be transmitted in response to scan requests from other devices.

6. Set Scan Response Data: The scan response data is associated with the advertising instance using the function ble_gap_ext_adv_set_data.

7. Start Extended Advertising: The function ble_gap_ext_adv_start is called to start the extended advertising for the specified instance.

Overall, this code configures and starts extended advertising with specific parameters for the given instance. It also sets scan response data to be sent along with advertising packets.

### Why Extended Advertisement
In Bluetooth 4.0, the advertising payload was a maximum of 31 octets. In Bluetooth 5, it is increased to 255 octets by adding additional advertising channels and new advertising PDUs.
This removes the need to duplicate the data payload on all three advertising channels while allowing considerably more advertising data in the area before running into coexistence issues.

Bluetooth 5 provides three low-energy PHYs:

- LE 1M PHY –1M/s bit rate; uncoded (each bit maps to a single radio symbol). The same PHY is used in Bluetooth 4.0.
- LE Coded PHY (new) – Supports 1M/s symbol rate with error correction coding. Used for Bluetooth 5’s “four times the range”.
- LE 2M PHY (new) –2M/S symbol rate; uncoded. Used for Bluetooth 5’s “2 times the speed”.
So with two new PHYs, 4 times the range and 2 times the speed is achieved. 

## GAP Events in bleprph
We have set the  `bleprph_gap_event()` as callback for `ble_gap_adv_start()` method. Various events are handled in the `bleprph_gap_event()`.Their list is as follows:
1. BLE_GAP_EVENT_CONNECT: This case handles when a new connection is established or a connection attempt fails. It prints connection status, and details about the connection, and, in case of failure, resume advertising. If the Connection was established then the connection descriptor is initiated using the method `ble_gap_conn_find()`.
2. BLE_GAP_EVENT_DISCONNECT: This case handles a disconnection event. It prints disconnection details and resumes advertising.
3. BLE_GAP_EVENT_CONN_UPDATE:  This case handles a connection parameter update event. It prints the updated connection parameters.
4. BLE_GAP_EVENT_ADV_COMPLETE: This case handles the completion of advertising. It resumes advertising when advertising completes.
5. BLE_GAP_EVENT_ENC_CHANGE: This case is activated when encryption is enabled or disabled for a connection. It displays the status of the encryption change and the connection descriptor. If encryption is enabled (when `CONFIG_EXAMPLE_ENCRYPTION` is defined), it initiates service discovery.
6. BLE_GAP_EVENT_NOTIFY_TX: This case handles a notification transmit event. It prints details about the transmitted notification.
7. BLE_GAP_EVENT_SUBSCRIBE: This case handles a subscription event. It prints details about subscription changes.
8. BLE_GAP_EVENT_MTU: This case is activated when the Maximum Transmission Unit (MTU) is updated for a connection. It prints the new MTU value and related information.
9. BLE_GAP_EVENT_REPEAT_PAIRING: The event occurs when we already have a bond with the peer, but it is attempting to establish a new secure link. It is convenient to just throw away the old bond and accept the new link.
 
These cases cover various events related to GAP and security management, allowing the application to respond appropriately to different situations during BLE communication.

## Conclusion
1. This example focuses on learning about GATT database configuration, handling GATT read and write operations, managing to subscribe events, understanding advertisement, and utilizing NimBLE APIs for SMP (Security Manager Protocol) related tasks.
2. In addition, this example showcases the security capabilities of the NimBLE stack. 
3. The configuration of SMP parameters, such as the device's I/O capabilities, bonding flag, Man-In-The-Middle (MITM) protection flag, Secure Connection Only mode, and enabling link encryption, can be easily set through menuconfig options.

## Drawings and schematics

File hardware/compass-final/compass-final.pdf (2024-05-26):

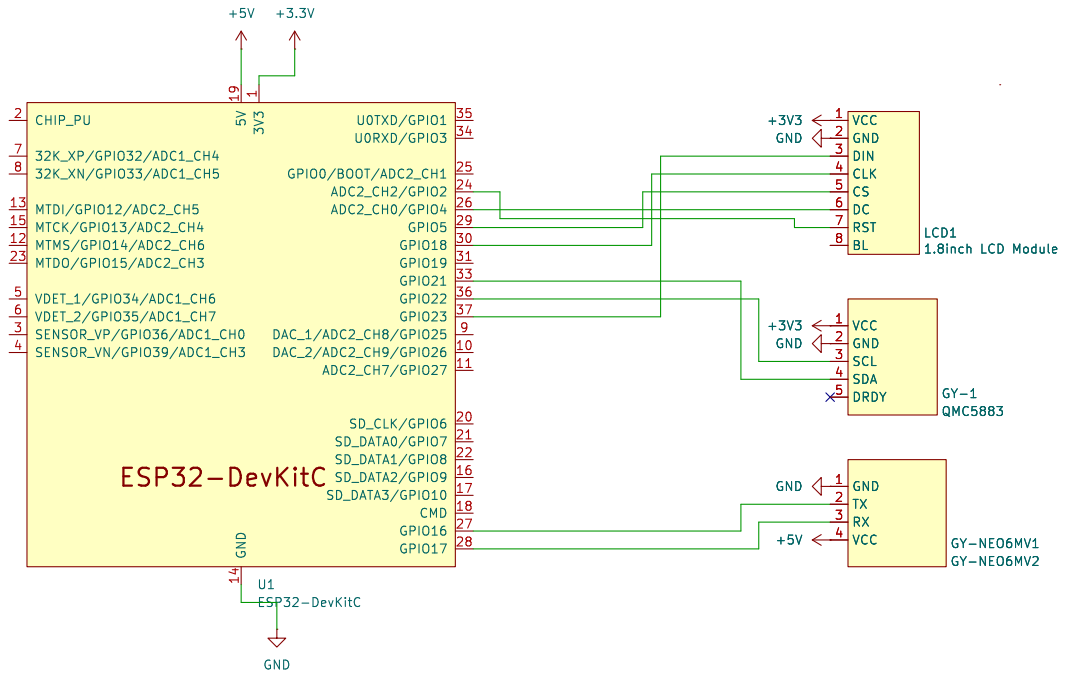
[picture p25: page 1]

Cybulski | Dominik Durkalec þÿMichaB

þÿWrocBawska Id: 1/1 Title: SmartCompass Prototype Final File: compass-final.kicad_sch Sheet: / Politechnika

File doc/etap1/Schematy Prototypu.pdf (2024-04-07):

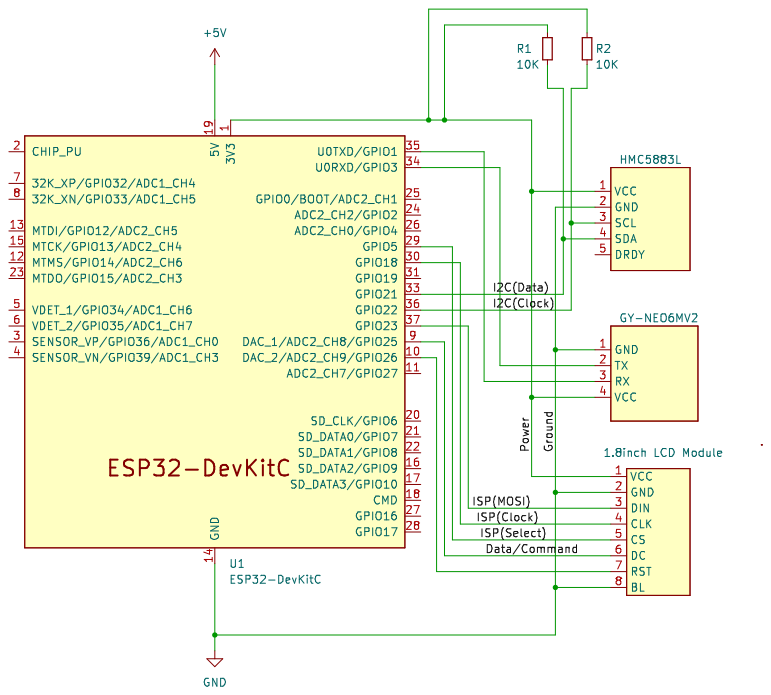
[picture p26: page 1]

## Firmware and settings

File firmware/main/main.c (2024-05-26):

#include "freertos/FreeRTOS.h"
#include <freertos/semphr.h>
#include "esp_log.h"

#include "compass_data.h"
#include "sc_ble.h"
#include "sc_display.h"
#include "sc_gps.h"
#include "sc_compass.h"
#include "sc_logic.h"

compass_data_t compass_data;
display_data_t display_data;

void log_compass_data() {
    ESP_LOGI("compass_data", "Position: %f, %f", compass_data.position.lat, compass_data.position.lon);
    ESP_LOGI("compass_data", "Bearing: %.2f [rad] %.2f [deg]", compass_data.bearing, compass_data.bearing_deg);
    ESP_LOGI("compass_data", "Path length: %lu", compass_data.path.length);
}

void
app_main(void) {
    compass_data = (compass_data_t) {
            .mutex = (SemaphoreHandle_t) xSemaphoreCreateMutex(),
            .position = (compass_position_t) {
                    .lat = 0.0f,
                    .lon = 0.0f
            },
            .bearing = 0.0f,
            .bearing_deg = 0.0f,
            .path = (compass_path_t) {
                    .length = 0
            },
            .position_updated = false
    };
    display_data = (display_data_t) {
            .mutex = (SemaphoreHandle_t) xSemaphoreCreateMutex(),
            .angle = 0,
            .next_wp = 0,
            .distance = 0,
            .finished = false
    };
    ESP_LOGI("main", "BLE init");
    sc_ble_init();
    ESP_LOGI("main", "Display init");
    sc_display_init();
    ESP_LOGI("main", "GPS init");
    sc_gps_init();
    ESP_LOGI("main", "Compass init");
    sc_compass_init();
    ESP_LOGI("main", "Logic init");
    sc_logic_init();
    while (1) {
        vTaskDelay(1000 / portTICK_PERIOD_MS);
        log_compass_data();
    }
}

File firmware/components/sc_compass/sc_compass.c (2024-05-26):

#include <sys/cdefs.h>
#include <math.h>
#include "sc_compass.h"

// Includes
#include "freertos/FreeRTOS.h"
#include "freertos/task.h"
#include "compass_data.h"
#include "esp_log.h"
#include "driver/i2c.h"

// Defines
#define TAG "sc_compass"
#define I2C_MASTER_NUM 1
#define I2C_MASTER_TIMEOUT_MS 1000

#define X_OFFSET -1711
#define Y_OFFSET 2895
#define ROT_OFFSET_RAD 4.18879f

// Bus variables
uint16_t compass_address;

static uint16_t autodetect_address() {
    return 0x0D; // Default address QMC5883L
}

static uint8_t compass_read_register(uint8_t reg) {
    uint8_t send_buf[8] = {0};
    uint8_t read_buf[8] = {0};
    // Set pointer to register
    send_buf[0] = reg; // Write mode
    send_buf[1] = reg; //  Location
    i2c_master_write_read_device(I2C_MASTER_NUM, compass_address, send_buf, 1, read_buf, 1,
                                 pdMS_TO_TICKS(I2C_MASTER_TIMEOUT_MS));
    return read_buf[0];
}

static void compass_read_registers(uint8_t *buf, uint8_t len) {
    for (uint8_t i = 0; i < len; ++i) {
        buf[i] = compass_read_register(i);
    }
}

static void compass_read_data_registers(uint8_t *buf) {
    uint8_t send_buf[1] = {0x00}; // First compass data register
    ESP_ERROR_CHECK(i2c_master_write_read_device(I2C_MASTER_NUM, compass_address, send_buf, 1, buf, 6,
                                                 -1));
}

static void configure_device() {
    ESP_LOGI(TAG, "Configuring device...");
    // Write to mode register
    uint8_t send_buf[8] = {0};
    send_buf[0] = 0x09; // Mode register
    send_buf[1] = 0x01; // Continuous mode
    ESP_ERROR_CHECK(i2c_master_write_to_device(I2C_MASTER_NUM, compass_address, send_buf, 2,
                                               -1));
    // Read all registers
    uint8_t reg_buf[12] = {0};
    compass_read_registers(reg_buf, 12);
    ESP_LOG_BUFFER_HEX(TAG, reg_buf, 12);
}

static void compass_calibrate(int16_t *output) {
    output[0] += X_OFFSET;
    output[1] += Y_OFFSET;
}

static float calculate_bearing(int16_t *output) {
    float x = output[0];
    float y = output[1];
    return atan2f(y, x) - ROT_OFFSET_RAD;
}

static float rad_to_deg(float rad) {
    float deg = rad * 180 / M_PI;
    while (deg < 0) {
        deg += 360;
    }
    return deg;
}

static void update_shared_data(int16_t *output) {
    float bearing = calculate_bearing(output);
    float bearing_deg = rad_to_deg(bearing);
    compass_data_t *compass_data_ptr = &compass_data;
    if (xSemaphoreTake(compass_data_ptr->mutex, portMAX_DELAY) == pdTRUE) {
        compass_data_ptr->bearing = bearing;
        compass_data_ptr->bearing_deg = bearing_deg;
        xSemaphoreGive(compass_data_ptr->mutex);
    }
}

_Noreturn static void sc_compass_task(void *args) {
    int16_t output[3];
    while (1) {
        vTaskDelay(pdMS_TO_TICKS(100));
        compass_read_data_registers((uint8_t *) output);
        compass_calibrate(output);
#ifdef CONFIG_COMPASS_LOGGING
        ESP_LOG_BUFFER_HEX(TAG, output, 6);
        ESP_LOGI(TAG, "X: %d, Y: %d, Z: %d", output[0], output[1], output[2]);
        ESP_LOGI("compass_calibration", "%d, %d, %d", output[0], output[1], output[2]);
#endif
        update_shared_data(output);
    }
}

void sc_compass_init() {
    ESP_LOGI(TAG, "Initializing I2C bus and device...");

    int i2c_master_port = I2C_MASTER_NUM;
    i2c_config_t conf = {
            .mode = I2C_MODE_MASTER,
            .sda_io_num = CONFIG_I2C_SDA,
            .sda_pullup_en = GPIO_PULLUP_DISABLE,
            .scl_io_num = CONFIG_I2C_SCL,
            .scl_pullup_en = GPIO_PULLDOWN_DISABLE,
            .master.clk_speed = CONFIG_I2C_SCL_SPEED_HZ,
    };

    ESP_ERROR_CHECK(i2c_param_config(i2c_master_port, &conf));
    ESP_ERROR_CHECK(i2c_driver_install(i2c_master_port, conf.mode, 0, 0, 0));
    ESP_LOGI(TAG, "I2C bus initialized");
    // Add device
    vTaskDelay(pdMS_TO_TICKS(500)); // Wait for device to boot
#ifdef CONFIG_COMPASS_AUTODETECT_ADDR
    compass_address = autodetect_address();
#else
    compass_address = CONFIG_COMPASS_ADDR;
#endif
    ESP_LOGI(TAG, "Compass connected at address %2x", compass_address);
    // Configure device
    configure_device();
    ESP_LOGI(TAG, "Compass initialized");
    // Start task
    xTaskCreate(sc_compass_task, "sc_compass_task", 4096, NULL, 1, NULL);
    ESP_LOGI(TAG, "Task started");
};

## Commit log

2024-04-07 Schematy dla prototypu i pilki KiCad
    PDF schematów umieszczony w folderze doc/etap1, natomiast kluczowe pliki KiCada w hardware/ki-cad. Możliwe, że zajdzie potrzeba udostępnienia dodatkowych plików
    [compass-schematics.kicad_sch]
2024-04-16 Createted sample project Based on esp-idf/eaxamples/bluetooth/nibmle/bleperph
2024-04-19 Added arduino-esp32.git submodule
2024-04-19 Revert "Added arduino-esp32.git submodule"
    This reverts commit eb84f7accbaf26a1bfd49bd888474e0d6288e07c.
2024-04-20 Ported example code to work with updated drivers
2024-04-21 Revert "Include back BLE before merge"
    This reverts commit 6e0e70897518c8d0813a345f2d1b8dcf0872dd32.
    [main.c]
2024-04-22 Basic I2C config and connection test
2024-04-25 Smooth animation of expanding track cards fixed
2024-05-03 Change device name (BLE)
2024-05-04 Helper for logging current compass state
2024-05-23 Rename button added to FilesScreen
2024-05-23 FileComponent buttons refactored
2024-05-23 Enable internal pullup (just in case)
2024-05-23 Change to old i2c api
2024-05-23 Change compass pins to default arduino pins (Wire.h)
2024-05-23 Add bearing to shared variable
2024-05-24 Final schematic
    [compass-final.kicad_pcb, compass-final.kicad_sch]
2024-05-25 Bug when trying send file and no device is connected fixed
2024-05-25 Change display pins for assembly
    [compass-final.kicad_sch]
2024-05-26 Add calibration script
2024-05-26 Change bearing variables to floats
2024-05-26 Update internal logic to save radian based angle and expect radian based bearing from compass
2024-05-26 Add smooth average filter
2024-06-09 Fill details about the components and add main schematics
